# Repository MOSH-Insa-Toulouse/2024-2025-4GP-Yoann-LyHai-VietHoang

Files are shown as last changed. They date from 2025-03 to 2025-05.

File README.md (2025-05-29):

# Projet : Capteur Graphite à Crayon

## Table des matières
- [Projet : Capteur Graphite à Crayon](#projet--capteur-graphite-à-crayon)
  - [Table des matières](#table-des-matières)
- [Contexte](#contexte)
- [Réalisation du projet](#réalisation-du-projet)
  - [1. Matériaux utilisés](#1-matériaux-utilisés)
  - [2. Simulation électronique en utilisant LTSpice](#2-simulation-électronique-en-utilisant-ltspice)
    - [2.1 Fonctionnalité de condition nominale](#21-fonctionnalité-de-condition-nominale)
    - [2.2 Modélisation du capteur](#22-modélisation-du-capteur)
    - [2.3 Résultats visuels](#23-résultats-visuels)
    - [2.4 Simulation du signal alternatif](#24-simulation-du-signal-alternatif)
  - [3. Conception du circuit PCB en utilisant KiCad](#3-conception-du-circuit-pcb-en-utilisant-kicad)
    - [3.1 Réalisation des symboles et empreintes](#31-réalisation-des-symboles-et-empreintes)
    - [3.2 Réalisation du schéma électronique](#32-réalisation-du-schéma-électronique)
    - [3.3 Réalisation du PCB](#33-réalisation-du-pcb)
  - [4. Code Arduino](#4-code-arduino)
  - [5. Application Android codée avec MIT App Inventor](#5-application-android-codée-avec-mit-app-inventor)
    - [5.1. Initialisation](#51-initialisation)
    - [5.2. Composantes dans l'interface](#52-composantes-dans-linterface)
      - [Connection du Bluetooth:](#connection-du-bluetooth)
    - [Le bouton pour le capteur industriel (FlexSensor) et le capteur graphite](#le-bouton-pour-le-capteur-industriel-flexsensor-et-le-capteur-graphite)
    - [Le bouton "Mesure"](#le-bouton-mesure)
    - [Le bouton "Reset"](#le-bouton-reset)
    - [Bloc principal - Timer](#bloc-principal---timer)
    - [Le Graphique](#le-graphique)
  - [6. Réalisation du Shield](#6-réalisation-du-shield)
  - [7. Banc de test](#7-banc-de-test)
    - [7.1 Physique derrière le capteur en graphite](#71-physique-derrière-le-capteur-en-graphite)
    - [7.2 Résultats de mesures](#72-résultats-de-mesures)
  - [8. Datasheet](#8-datasheet)
- [Conclusion](#conclusion)
- [Références](#références)
- [Contacts](#contacts)
  - [Étudiants](#étudiants)
  - [Enseignants](#enseignants)

---

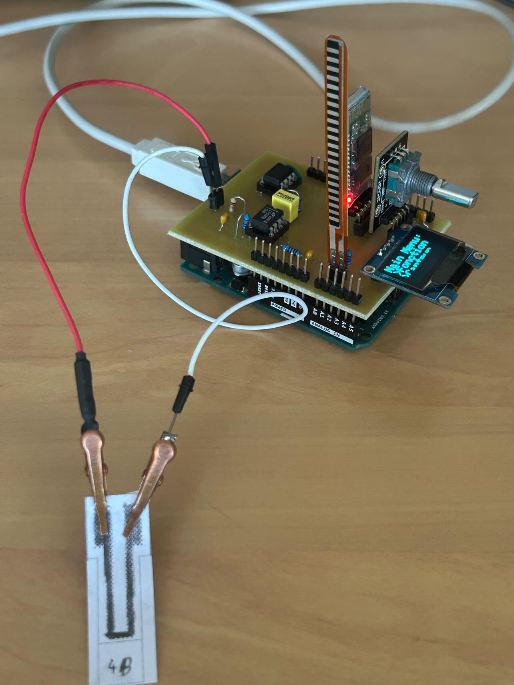
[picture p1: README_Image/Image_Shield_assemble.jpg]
Image de l'ensemble carte Arduino et capteur en graphite


# Contexte
Ce projet vise à développer un capteur basé sur du graphite de crayon de papier pour des applications en instrumentation. L'objectif est d'explorer les propriétés conductrices du graphite et de les exploiter dans un circuit électronique interactif.

---

# Réalisation du projet

---

## 1. Matériaux utilisés

Dans ce projet, nous utilisons des composants électroniques et des modules disponibles dans la salle d'instrumentation avec une carte Arduino UNO. Tous les composants sont listés ci-dessous :
   * 1 carte Arduino UNO Rev 3
   * 1 module Bluetooth (HC-05)
   * 1 encodeur rotatif (Keyes KY-040)
   * 1 écran OLED (SSD 1306)
   * 1 capteur de flexion commercial (LLC 1070)
   * 1 capteur en graphite fait à l'aide de la mine d'un crayon de papier
   * 1 amplificateur de transimpédance (LTC1050)
   * 1 potentiomètre numérique (MCP41100)
   * 2 supports IC pour le potentiomètre et l'amplificateur
   * 1 résistance 1kΩ, 1 résistance 10kΩ, 2 résistances 100kΩ
   * 3 condensateurs 100nF, 1 condensateur 1µF

---

## 2. Simulation électronique en utilisant LTSpice

### 2.1 Fonctionnalité de condition nominale

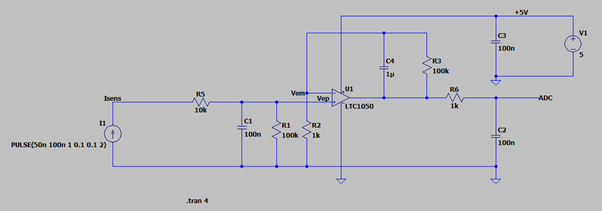
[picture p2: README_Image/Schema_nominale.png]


Le courant d’entrée Isens varie entre 50 nA et 100 nA, ce qui entraîne une variation de la tension Vep appliquée à l’entrée non-inverseur V+ du LTC1050, entre 5 mV et 10 mV.

Le gain de l’amplificateur du LTC1050 est défini par : G = 1 + R3/R2 = 101. Par conséquent, la valeur de la tension de sortie du LTC1050 varie entre 0.5 V et 1 V.

Simulation gain

Au départ, le signal exprimé en décibels est de 140 dB, ce qui correspond à :  
20 log(VADC / Isens).

Le microcontrôleur utilisé est un Arduino UNO, basé sur un microcontrôleur AVR avec une fréquence d’échantillonnage maximale fech = 200 kHz.  
Comme la conversion analogique-numérique se fait sur 13 bits, la fréquence d’échantillonnage réelle est limitée à 15.4 kHz.

D'après le théorème de Nyquist, la fréquence maximale du signal que l'on peut correctement numériser doit donc être inférieure à la moitié de cette valeur :  
fsignal < fech/2 = 7.7 kHz.

### 2.2 Modélisation du capteur

Le bruit à 50 Hz, généré notamment par l'écran TFT (bruit de type secteur), est clairement observé dans le spectre du signal. Pour l’atténuer, on agit sur le condensateur C4 du filtre passe-bas.

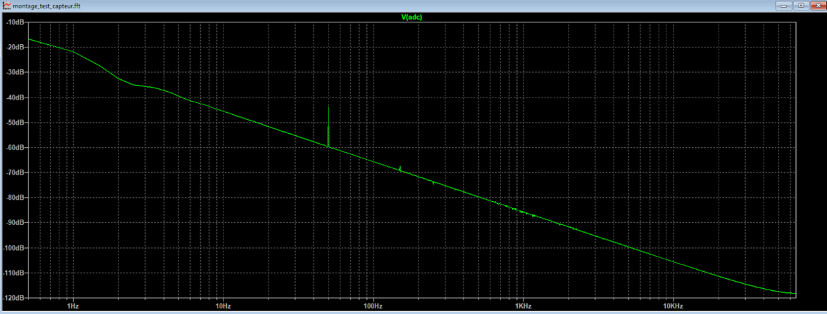
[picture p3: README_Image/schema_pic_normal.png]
Pic normal


- Lorsque la valeur de C4 est augmentée à 10 µF, le pic de bruit à 50 Hz est fortement réduit, ce qui indique une amélioration de l’atténuation dans les basses fréquences.

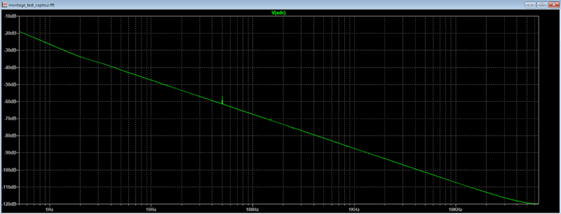
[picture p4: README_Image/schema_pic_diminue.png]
Pic diminue


- En revanche, si on diminue la valeur de C4, le bruit augmente, montrant que la fréquence de coupure du filtre remonte et que le bruit secteur passe plus facilement.

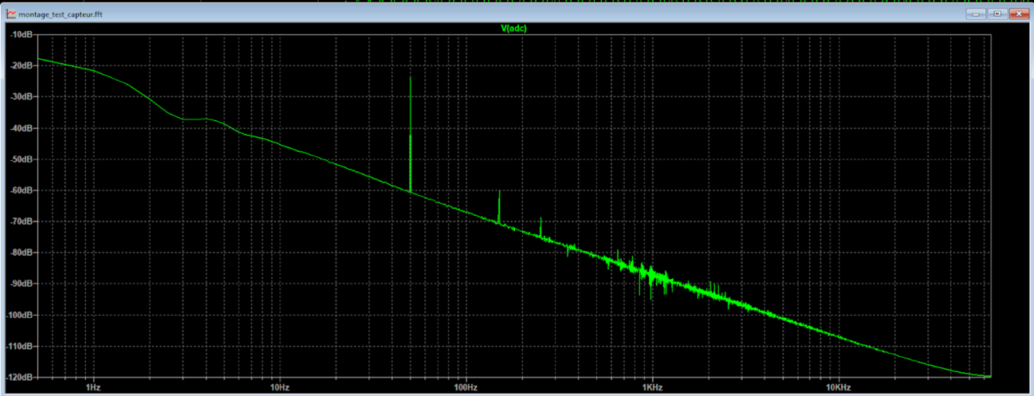
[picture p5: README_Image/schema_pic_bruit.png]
Pic bruit


### 2.3 Résultats visuels

Une photo démontrant que notre circuit permet une amplification efficace du signal délivré par le capteur :

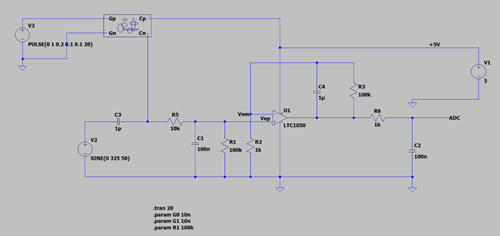
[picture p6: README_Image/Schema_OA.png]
Schema OA


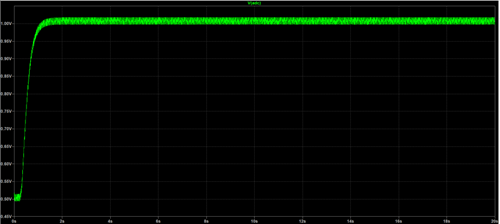
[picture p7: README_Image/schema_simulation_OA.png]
Simulation OA


### 2.4 Simulation du signal alternatif

Ensuite, on présente la réponse du circuit lorsque l'on simule un courant alternatif, afin de vérifier que le bruit est correctement filtré :

Le bruit du réseau est atténué d'environ 72 dB à 50 Hz.

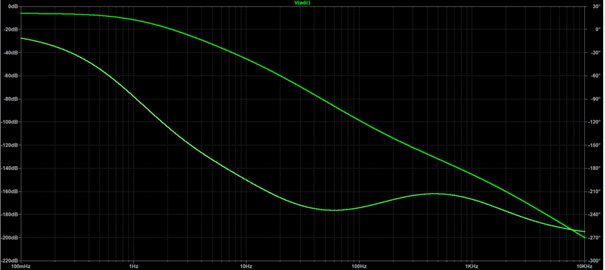
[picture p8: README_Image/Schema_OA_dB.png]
Schema OA dB


---

## 3. Conception du circuit PCB en utilisant KiCad

Afin de concevoir le circuit électronique, le logiciel en libre accès KICAD a été utilisé. L'ensemble des fichiers KiCad est disponible dans le dossier [Capteur_KICAD](./Capteur_KICAD).

### 3.1 Réalisation des symboles et empreintes

Pour commencer notre PCB (Printed Circuit Board), il est nécessaire de créer les symboles et les empreintes des composants qui ne sont pas disponibles dans la bibliothèque de KiCad. Nous avons réalisé les symboles du module Bluetooth, de l'encodeur rotatif, de l'écran OLED, du capteur de flexion et du capteur en graphite, afin de les ajouter au schéma de connexion. Ensuite, ces symboles ont été associés à une empreinte trouvée sur des sites de libre téléchargement.

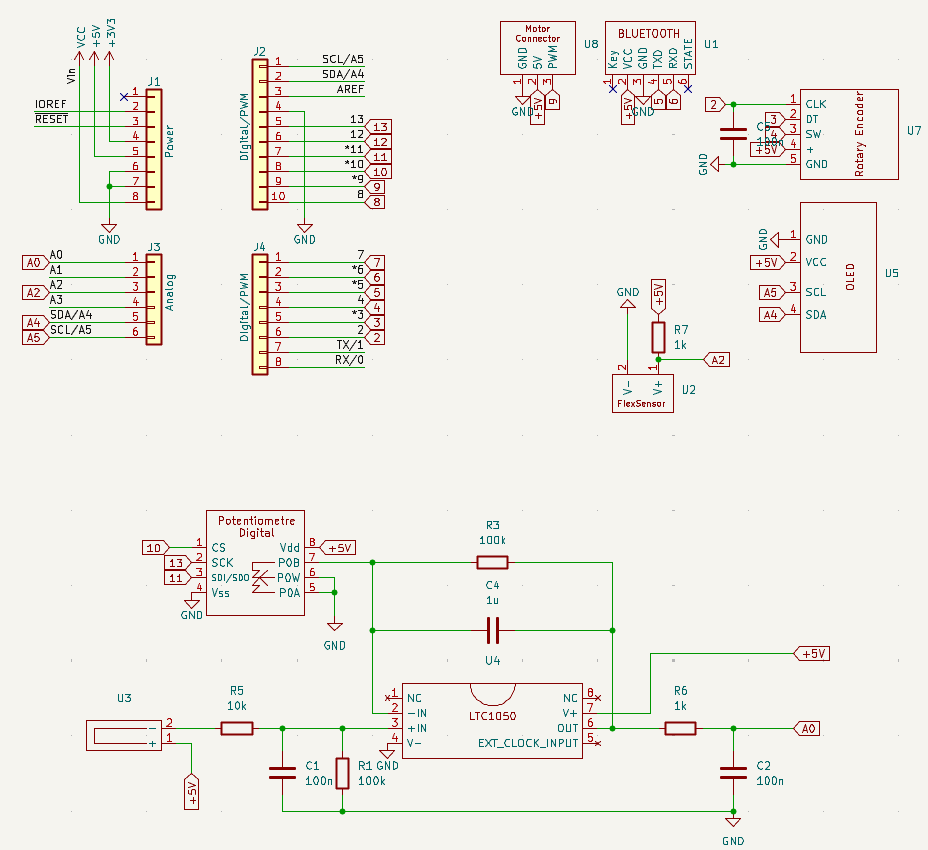
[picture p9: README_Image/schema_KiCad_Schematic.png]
Schéma électonique réalisé sur KiCad


### 3.2 Réalisation du schéma électronique

Ensuite, le schéma électronique est à construire. Dans cette partie, les différentes connexions entre composants sont définies et les pins de la carte Arduino sont attribués à chacun des composants.

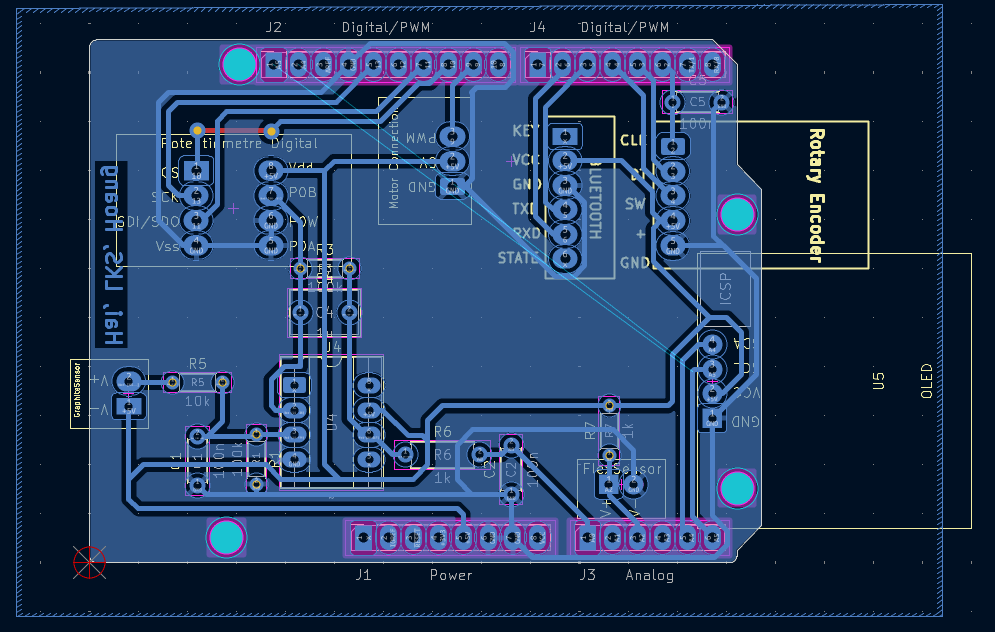
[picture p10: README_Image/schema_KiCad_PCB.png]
Schéma de routage du PCB sur KICAD


### 3.3 Réalisation du PCB

L'objectif ici était d'allouer un branchement sur les entrées d'une carte Arduino UNO à chaque module. Nous avons aussi pour but de faire le moins possible de via (pont traversant permettant de chavaucher un routage).
Le circuit imprimé a été dessiné avec une attention particulière portée à la disposition des pistes pour minimiser les couplages parasites et faciliter le routage manuel.

Schéma Conception du PCB sur KICAD

Les contraintes de branchement ont été les suivantes:
  * Encoder: pin clk -> pin 2 (Arduino)
  * Bluetooth: pin TXD -> la pin 5 (pin RXD de l'Arduino)
               pin RXD -> la pin 6 (pin TXD de l'Arduino)
  * Potentiomètre digital: pin SCK -> pin 13 (pin SCK de l'Arduino)
                           pin SDI -> pin 11 ()
  * FlexSensor: sur une pin analogue (A2 choisi)
  * Capteur Graphite: sur une pin analogue (A0 choisi)

Ensuite, l'impression du circuit s'est ensuite faite par méthode chimie:
  * Plaque de cuivre/résine dont la face en cuivre est enduite d'une résine photosensible;
  * Insolation de la résine sur les parties du cuivre non voulue;
  * Attaque chimique dans un bain révélateur;
  * Rinçage du circuit;

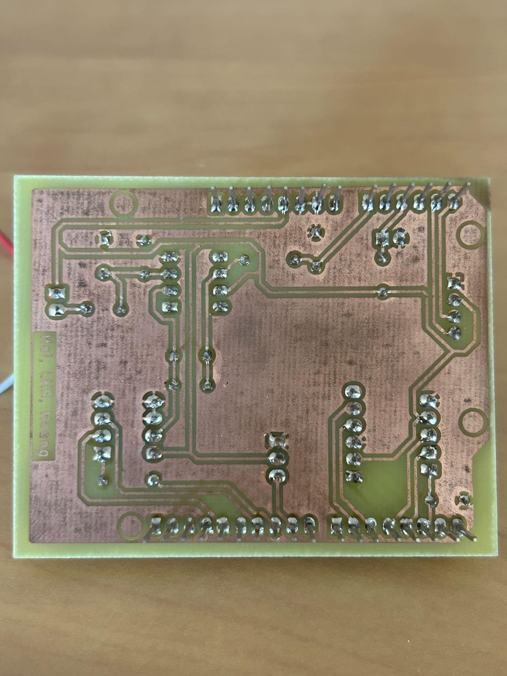
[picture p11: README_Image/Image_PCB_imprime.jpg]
Image montrant le PCB imprimé. Les soudures des composants sont aussi visibles


---

## 4. Code Arduino

Le code Arduino permet de lire les valeurs du capteur en graphite, de gérer l'affichage d'un Menu sur l'écran OLED, la communication par Bluetooth avec l'application Android (voir section [5. Application Android codée avec MIT App Inventor](#5.-Application-Android-codée-avec-MIT-App-Inventor)) et le contrôle via l'encodeur rotatif.
Le code arduino est disponible dans le dossier [Capteur_Arduino](./Capteur_Arduino).

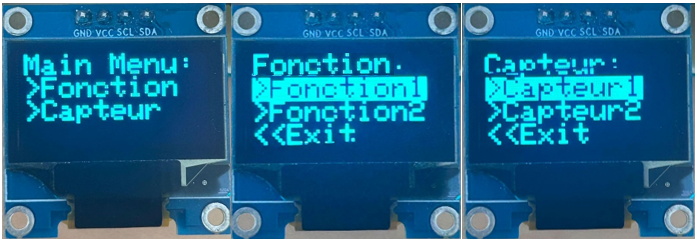
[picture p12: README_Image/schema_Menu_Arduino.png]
Image du menu


---

## 5. Application Android codée avec MIT App Inventor

Une application mobile a été développée pour :
- Recevoir les données en Bluetooth,
- Afficher les mesures en temps réel,
- Interagir avec le capteur de manière intuitive.
  
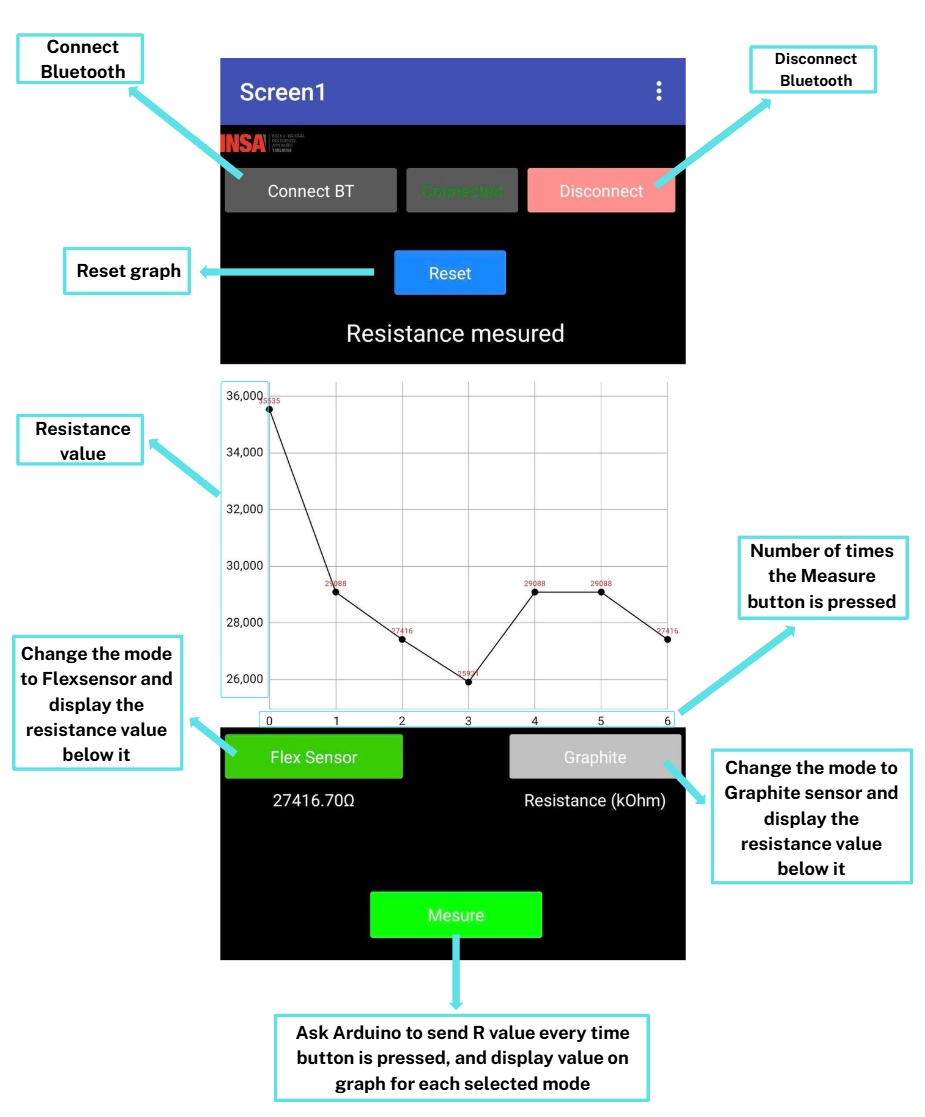
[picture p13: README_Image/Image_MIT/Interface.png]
Interface


### 5.1. Initialisation

  Nous avons déclaré les variables initiales utilisées dans le programme:

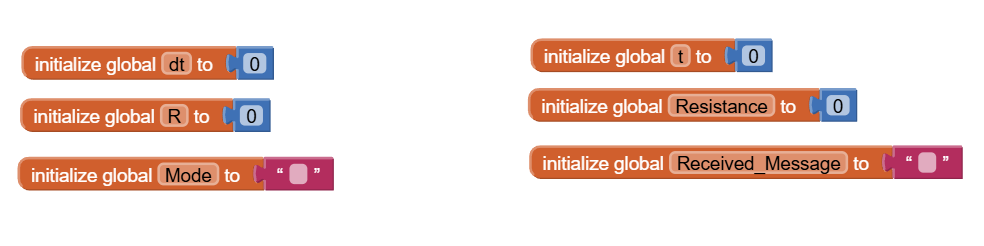
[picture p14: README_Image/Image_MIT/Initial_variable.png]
Variable initial
  

  Puis nous avons initialisé le programme:

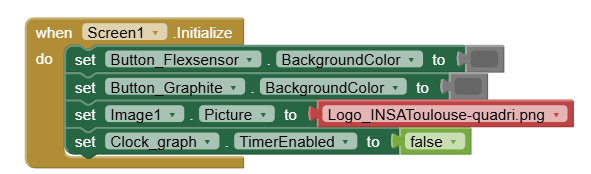
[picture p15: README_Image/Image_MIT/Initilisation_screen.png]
Demarrer screen
  

### 5.2. Composantes dans l'interface
---
#### Connection du Bluetooth:

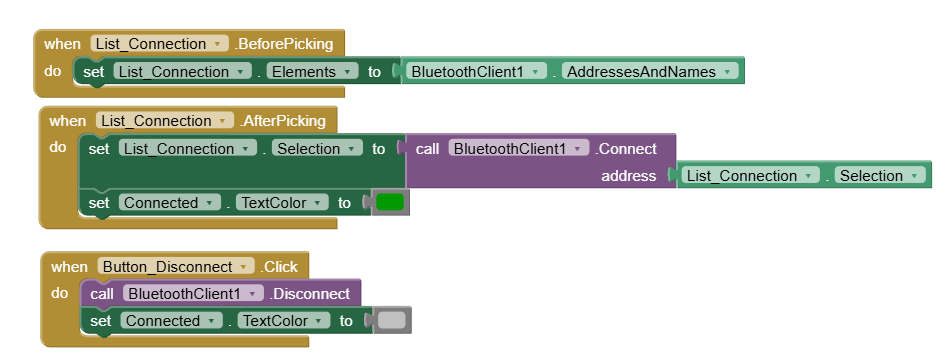
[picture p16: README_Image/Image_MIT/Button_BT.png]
Bouton BT

Le bouton « List_Connection » permet de sélectionner le module Bluetooth auquel on souhaite se connecter. Le bouton « Button_Disconnect » permet également de déconnecter le module Bluetooth sélectionné.

---

### Le bouton pour le capteur industriel (FlexSensor) et le capteur graphite

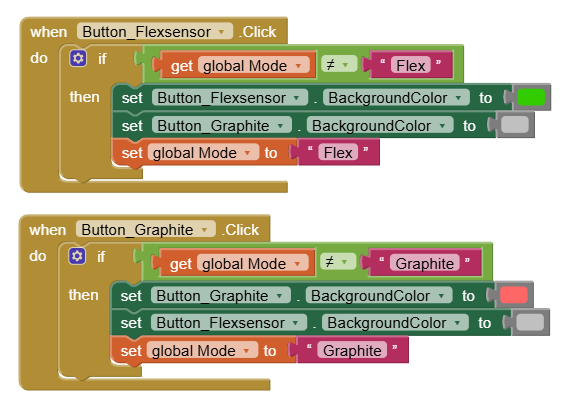
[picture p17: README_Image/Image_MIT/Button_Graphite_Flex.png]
Bouton Flex_Graphitesensor


Ces bouton permet de choisir le capteur que l'on veut afficher leur valeurs.

---
### Le bouton "Mesure"
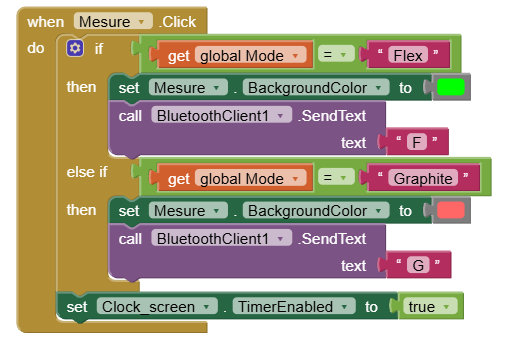
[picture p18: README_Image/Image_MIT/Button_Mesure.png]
Bouton Mesure


Ce bouton permet d'envoyer un message vers l'arduino via bluetooth pour lui demande de renvoyer les valeurs de resistances dependant le mode du capteur choisi.

---
### Le bouton "Reset"
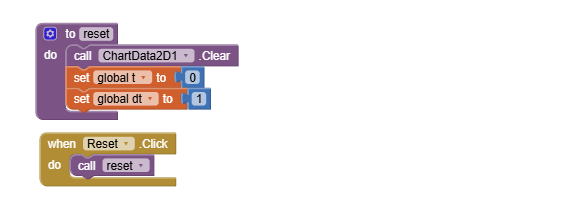
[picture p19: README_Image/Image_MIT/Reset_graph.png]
Reset Graph


Ce bouton permet de réinitialiser le graph.

---
### Bloc principal - Timer
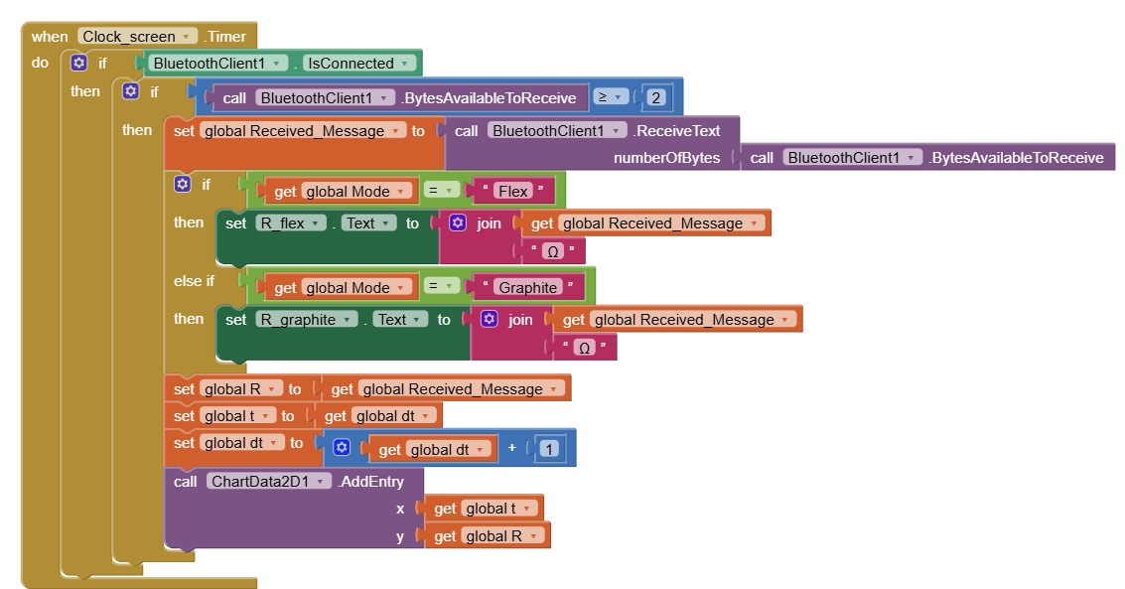
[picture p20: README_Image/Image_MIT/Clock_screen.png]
Timer

Pour pouvoir récupérer automatiquement des données, on commande séquentiellement Arduino de nous evoyer les données. Pour cela, on utilise le composante "Clock"dans MIT. 

---
### Le Graphique
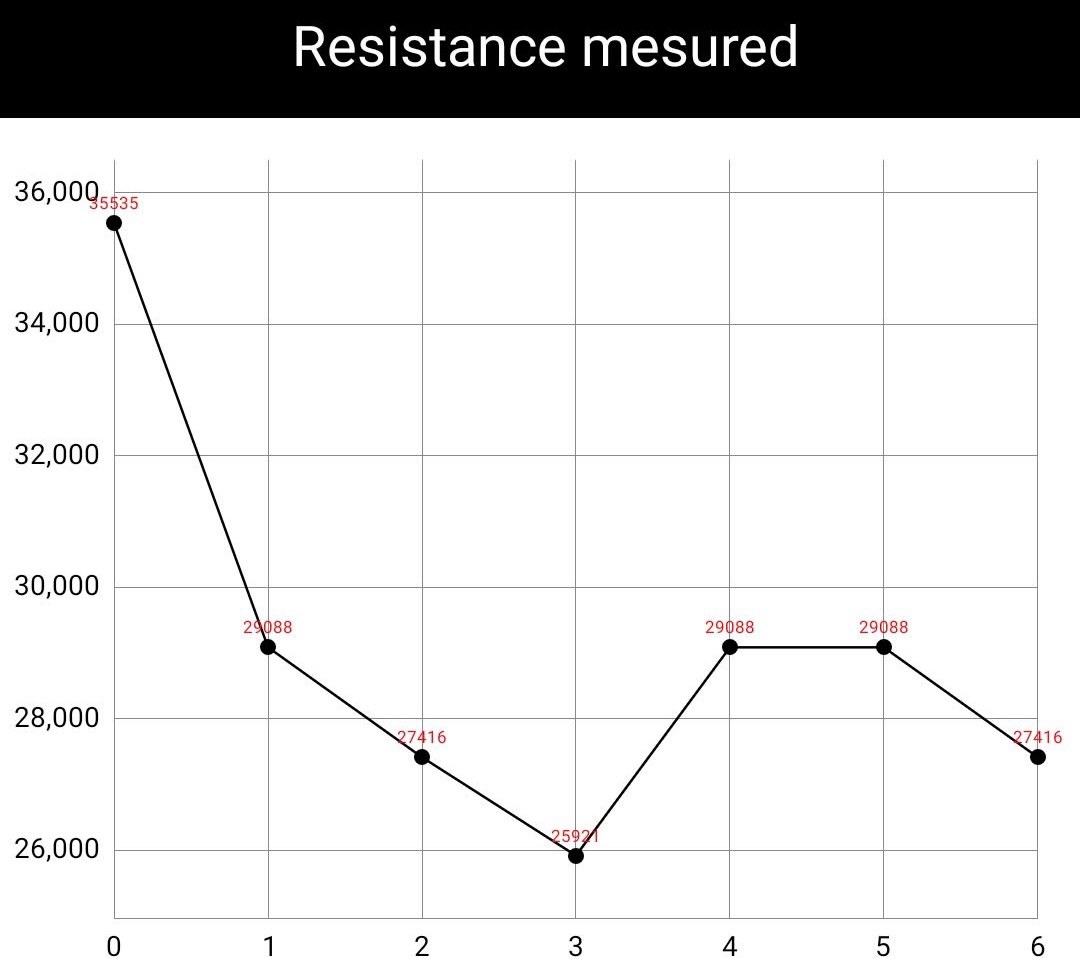
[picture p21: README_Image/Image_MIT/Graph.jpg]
Graph


Le graphique montre le variation de résistance du capteur FlexSensor et du capteur graphite à chaque mesure.

## 6. Réalisation du Shield

Pour la réalisation du shield, nous avons manuellement soudé l'ensemble des modules arduino et composants électroniques (résistances, capacités, amplificateur opérationnel) au PCB imprimé. (voir section [3.4 Réalisation du PCB](#34-réalisation-du-pcb)).

Le Shield réalisé intègre un amplificateur de signal LTC1050 pour amplifier les faibles signaux des capteurs avec précision, un encodeur rotatif permettant de naviguer dans le menu et de modifier les valeurs de résistance via un potentiomètre, un écran OLED pour afficher clairement les menus et les informations, ainsi qu’un module Bluetooth assurant la communication sans fil avec un téléphone portable pour le contrôle et la supervision à distance du système.

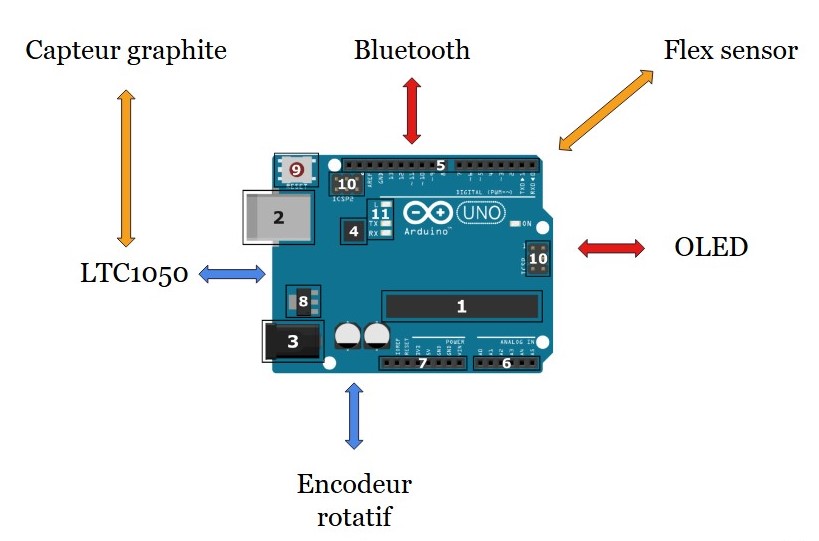
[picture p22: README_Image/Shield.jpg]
shield


---

## 7. Banc de test

Afin de valider le fonctionnement du système, plusieurs tests ont été réalisés :
- Mesure des signaux et tensions aux bornes des capteurs et calcul de résistance.
- Test de communication Bluetooth.
- Et prise de mesures de résistance issues du capteur en graphite.

Un modèle 3D composé de fentes circulaires de différents rayons est utilisé pour le banc de test. En insérant le capteur dans ces fentes, une déformation est induite en fonction de son orientation (traction ou compression). La déformation est inversement proportionnelle au rayon des fentes circulaires, selon la relation suivante : ε = e / R

  Où :  
  - ε : déformation 
  - e : allongement imposé  
  - R : rayon de la fente (0,2 mm)

Ce système permet de contrôler précisément la déformation du capteur en choisissant simplement un rayon de fente spécifique.

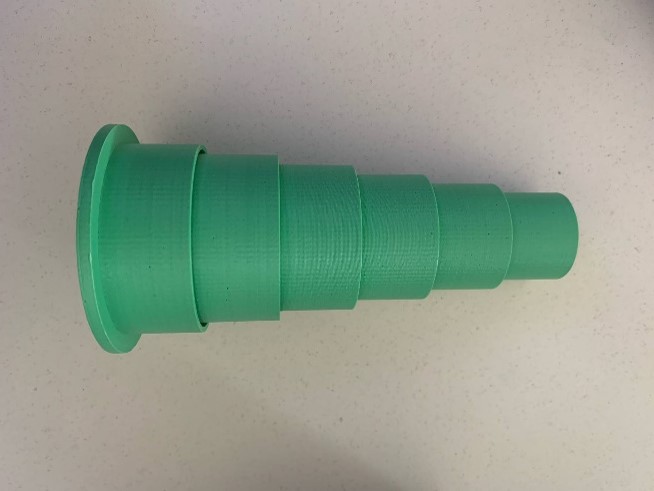
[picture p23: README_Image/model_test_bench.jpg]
model_test_bech


### 7.1 Physique derrière le capteur en graphite

Une variation de la résistance du capteur est attendue lorsque ce dernier est déformé. Cette variation est notamment dû au rapprochement ou à l'éloignement des atomes de carbone.
Lorsque le capteur est mis en tension, les atomes de carbone ont tendance à s'écarter. Ainsi, moins d'atome sont en contact afin de créer une chaîne reliant les deux extrémités du cpateur. Les électrons passent plus difficilement, la résistance augmente donc.
Lorsque le capteur est mis en compression, les atomes de carbone se rapprochent. La configuration est plus favorable à la création de chaîne reliant les deux extrémités du capteur. Les électrons passent plus facilement, la résistance diminue donc.
Par ailleurs, il est attendu à ce que la résistance diminue en même temps que la dureté du crayon de papier augmente. Cela peut simplement s'expliquer par une réduction de la présence de carbone.

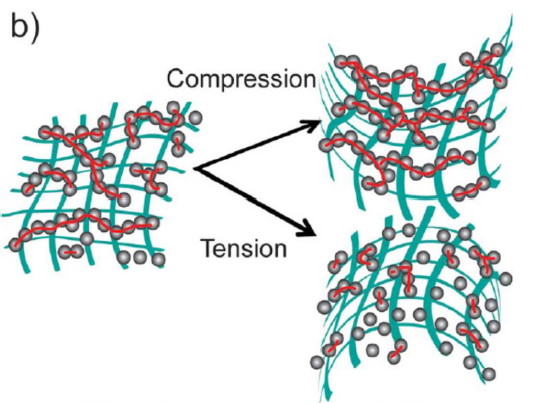
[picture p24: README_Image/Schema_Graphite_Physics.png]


La résistance peut s'exprimer comme suivant:

Schéma

  Où :
  - "l" la longueur de la couche de nanoparticule (graphite) ;
  - "a" le paramètre de maille de la matrice cubique centrée du graphite ;
  - "w" la largeur, et "d" l'épaisseur du film.
Quant à la résistance "R12", elle est obtenue en posant les équations de mécanique quantique appliquée à des nanoparticules :

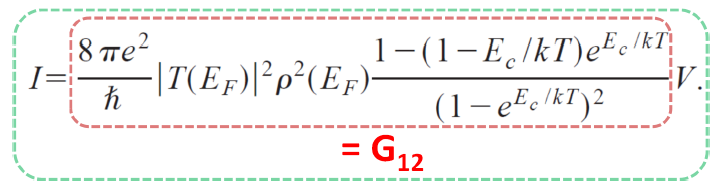
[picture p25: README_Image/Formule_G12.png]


Schéma

Pour plus d'informations, les sources utilisées sont fournies dans la rubrique [Références](#références).

### 7.2 Résultats de mesures

Par la suite, nous avons caractérisé notre capteur en graphite afin de retrouver les résultats de l'étude dont la source est donnée ci-dessus. La tension aux bornes du capteur est mesurée, puis convertie en valeur de résistance. Cette valeur de résistance est affichée en fonction de la déformation appliquée sur le capteur.
Les graphiques ci-dessus montrent la variation relative de la valeur du capteur en fonction de la déformation dans deux modes : traction et compression. Des droites de régression linéaire passant par l’origine ont été tracées. Ces lignes théoriques démontrent que la valeur de ΔR/R₀ varie linéairement avec la déformation.

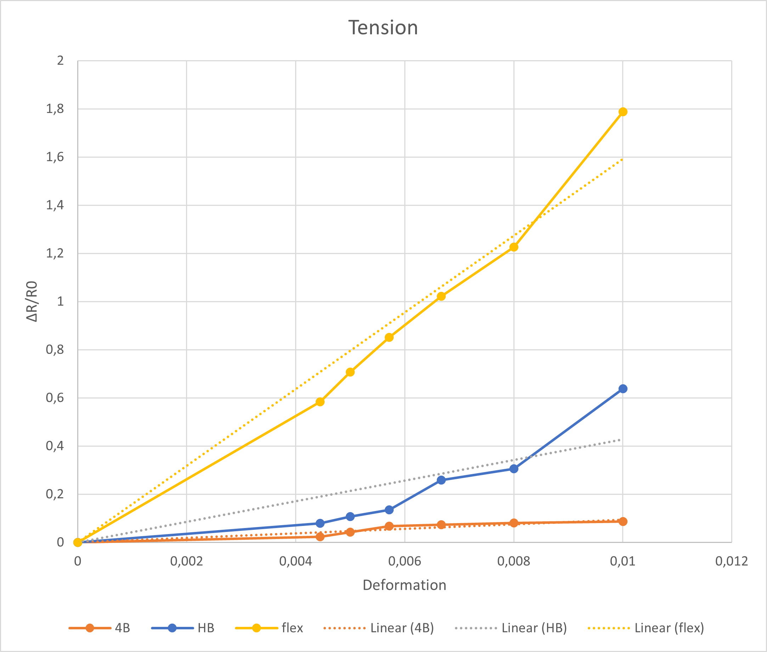
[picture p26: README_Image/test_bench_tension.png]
test_bench_tension


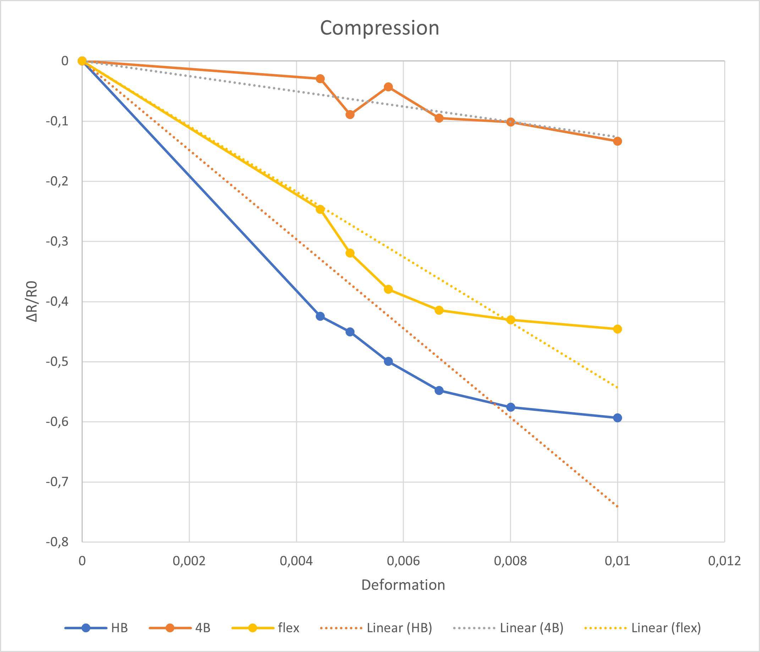
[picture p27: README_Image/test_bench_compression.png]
test_bench_compression


---

## 8. Datasheet
Les fiches techniques des principaux composants (LTC1050, HC-05, écran OLED, etc.) sont disponibles dans le dossier [datasheet_graphit_sensor.pdf](./Datasheet/datasheet_graphit_sensor.pdf) du projet. Par ailleurs, une documentation sur notre capteur graphite est disponible sur ce Github.

---

# Conclusion
Ce projet démontre la faisabilité d’un capteur à base de graphite de crayon pour des applications d’instrumentation. Le prototype final est capable de détecter des variations de résistance liées à la pression exercée sur le graphite. Néanmoins, la faible répétabilité des mesures et de la confection du capteur en graphite ne permet pas une industrialisation. On note aussi que durant le test, le graphite du capteur est en contact avec les parois. Cela pourrait engendrer un retrait de graphite à chaque insertion.
Les points d'amélioration pouvant être apportés sont : une amélioration du banc de test, la normalisation du dépôt de graphite.

Une documentation de notre capteur est aussi disponible ([Documentation Capteur Graphite](./Datasheet/Datasheet_graphit_sensor.pdf))

---

# Références
- Fiches techniques des composants (HC-05, Keyes KY-040, SSD 1306, LLC 1070, LTC1050, MCP41100)
- Documentation Arduino
- Tutoriels MIT App Inventor
- Outils de simulation LTSpice et KiCad

<ins>Sources sur l'étude du capteur en graphite :</ins>

"Pencil Drawn Strain Gauges and Chemiresistors on Paper
Cheng-Wei Lin*, Zhibo Zhao*, Jaemyung Kim & Jiaxing Huang
Department of Materials Science and Engineering,
Northwestern University 2220 Campus Drive, Evanston, IL, 60208, USA.
SCIENTIFIC REPORTS | 4 : 3812 | DOI: 10.1038/srep03812 - 2014"

"Electron transport in nanoparticle assemblies
K.-H. Müller1, J. Herrmann2, G. Wei1, B. Raguse1, and L.Wieczorek1
1Future Manufacturing Flagship, 1CSIRO Materials Science and Engineering
Lindfield NSW2070, Australia
2NationalMeasurement Institute, Lindfield NSW 2070, Australia
978-1-4244-5262-0/10/$26.00 © 2010 IEEE - ICONN 2010"

"Percolation model for electron conduction in films of metal nanoparticles linked by organic molecules
K.-H. Müller,* J. Herrmann, B. Raguse, G. Baxter, and T. Reda
Commonwealth Scientific and Industrial Research Organization, Telecommunications and Industrial Physics,
Sydney 2070, Australia
PHYSICAL REVIEW B 66, 075417 (2002)"

---

# Contacts

## Étudiants
- **Yoann Lai Koun Sing** : laikouns@insa-toulouse.fr  
- **Viet Hoang Pham** : vpham@insa-toulouse.fr  
- **Ly Hai Hoang** : lhoang@insa-toulouse.fr  

## Enseignants
- **Jérémie Grisolia** : jeremie.grisolia@insa-toulouse.fr  
- **Arnauld Biganzoli** : arnauld.biganzoli@insa-toulouse.fr  
- **Cathy Crouzet** : crouzet@insa-toulouse.fr  
- **Benjamin Mestre** : benjamin.mestre@scalian.com

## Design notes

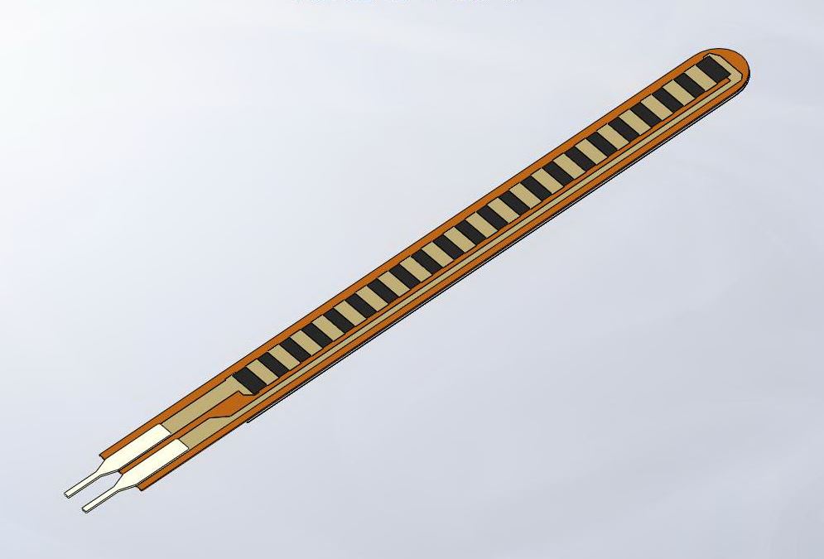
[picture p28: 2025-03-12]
Capteur_KICAD/Librairie_Model3D/flex-sensor-spectra-symbol-1.snapshot.2/Renderings/Flex Sensor.JPG

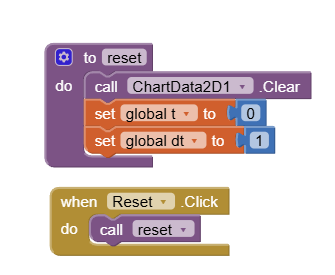
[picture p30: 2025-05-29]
README_Image/Image_MIT/Button_resetgraph.png

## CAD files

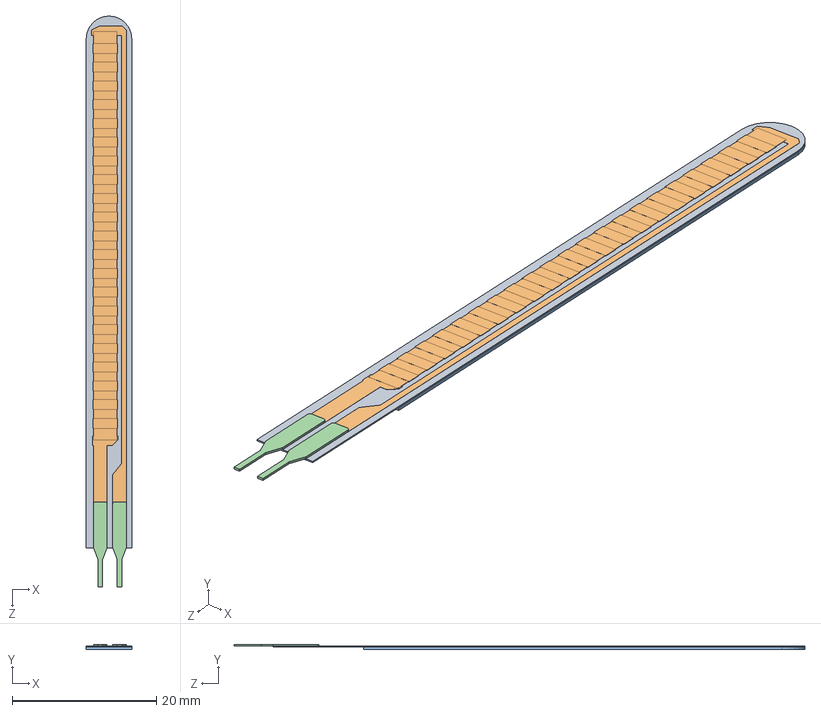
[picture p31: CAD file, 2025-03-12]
Capteur_KICAD/Librairie_Model3D/flex-sensor-spectra-symbol-1.snapshot.2/Flex Sensor/FlexSensor.SLDASM
6.35 x 0.648 x 79.3 mm
PlasticFilm
Flex_Sensor_Circuit
Plastic_Stiffner
GoldProngTerminal x 2

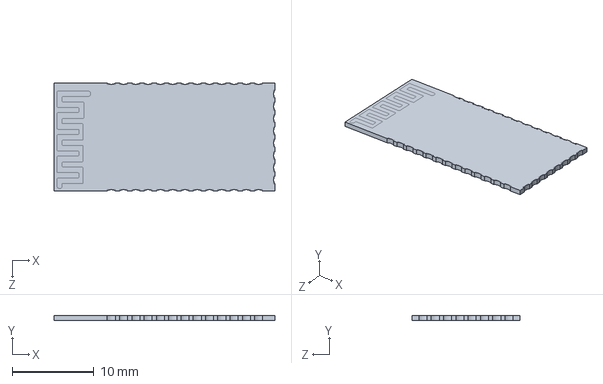
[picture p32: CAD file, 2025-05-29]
Capteur_KICAD/Librairie_Model3D/bluetooth-module-hc-05-1.snapshot.4/Bluetooth Module HC-05/HC-05 part3.SLDPRT
27.0 x 0.61 x 13.2 mm

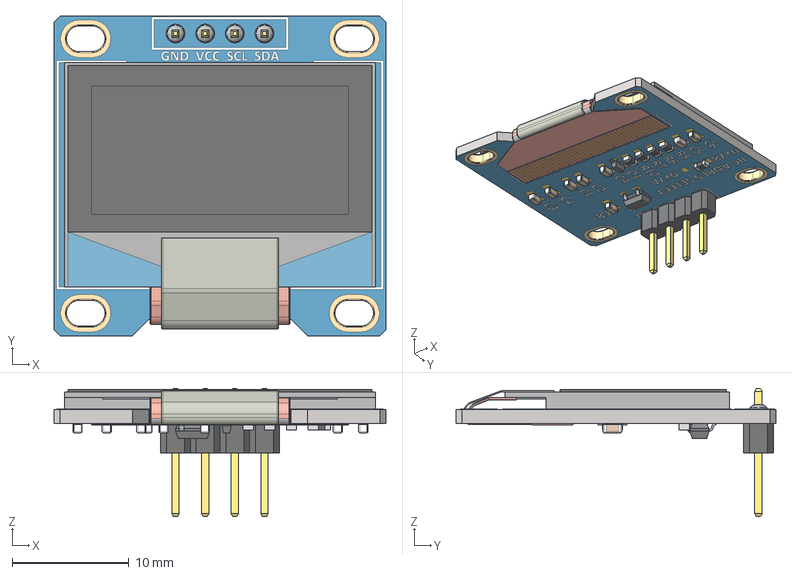
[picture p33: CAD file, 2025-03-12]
Capteur_KICAD/Librairie_Model3D/pantalla-oled-0-96-128x64-1.snapshot.7/Pantalla OLED 0.96'' 128x64.stp
28.4 x 27.4 x 11.0 mm
SOT-23_TOR
RES_CR16_MTK_1 x 4
RES_CR16_MTK
SOD323F_DIO

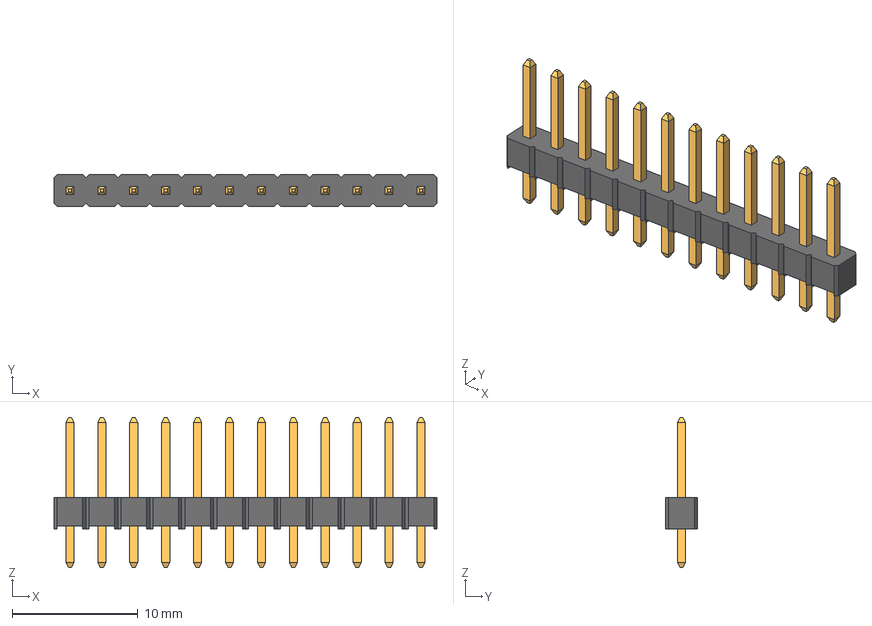
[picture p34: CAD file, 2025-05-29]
Capteur_KICAD/Librairie_Model3D/pin-header-male-2-54mm-different-pin-numbers-1.snapshot.2/12-Pin Header - Male - 2.54mm.step
30.5 x 2.54 x 11.9 mm

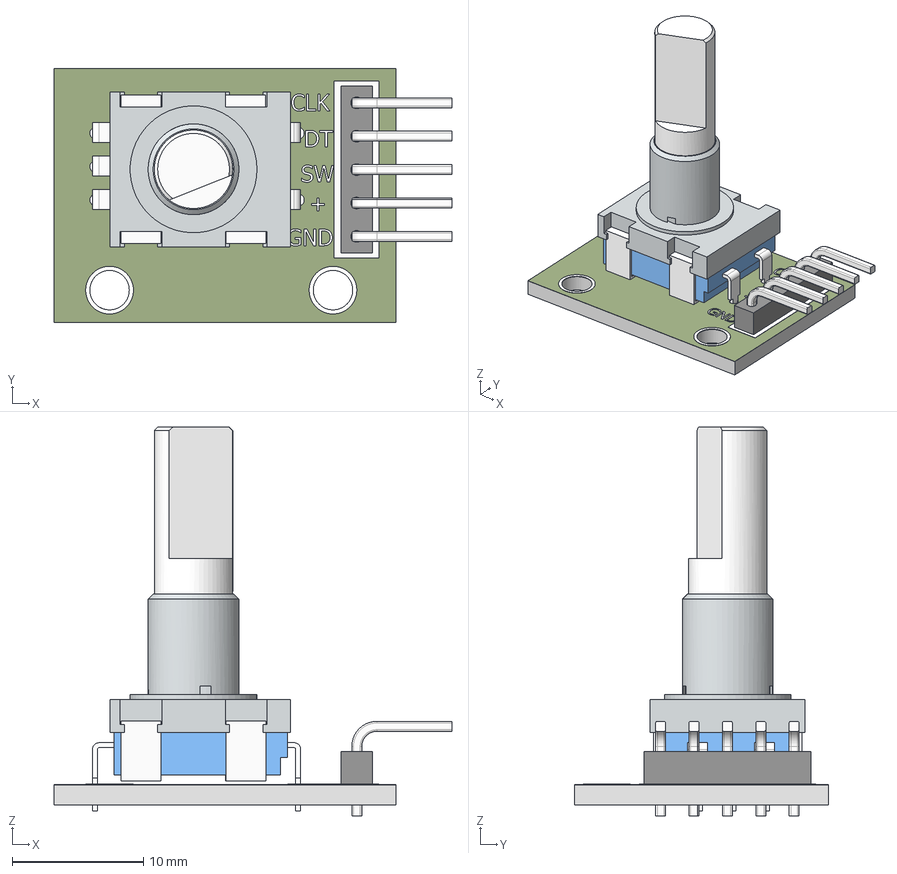
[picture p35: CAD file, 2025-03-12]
Capteur_KICAD/Librairie_Model3D/rotary-encoders-1.snapshot.1/rotary+encoder_17mm_hole_spc.stp
30.3 x 19.3 x 29.6 mm
pcb
mtg flange
body_encoder
5 pin header
90d pin_header x 5
decal_encoder
pins_encoder body_2 x 5
shaft_encoder

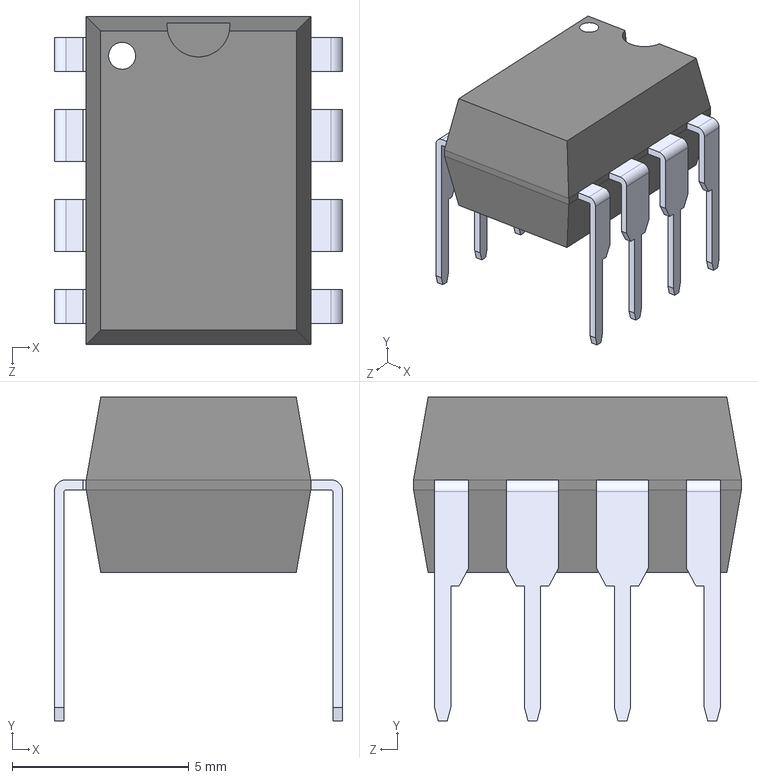
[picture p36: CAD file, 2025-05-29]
Capteur_KICAD/LTC1050ACN8_PBF/LTC1050ACN8_PBF.step
8.15 x 9.14 x 9.27 mm

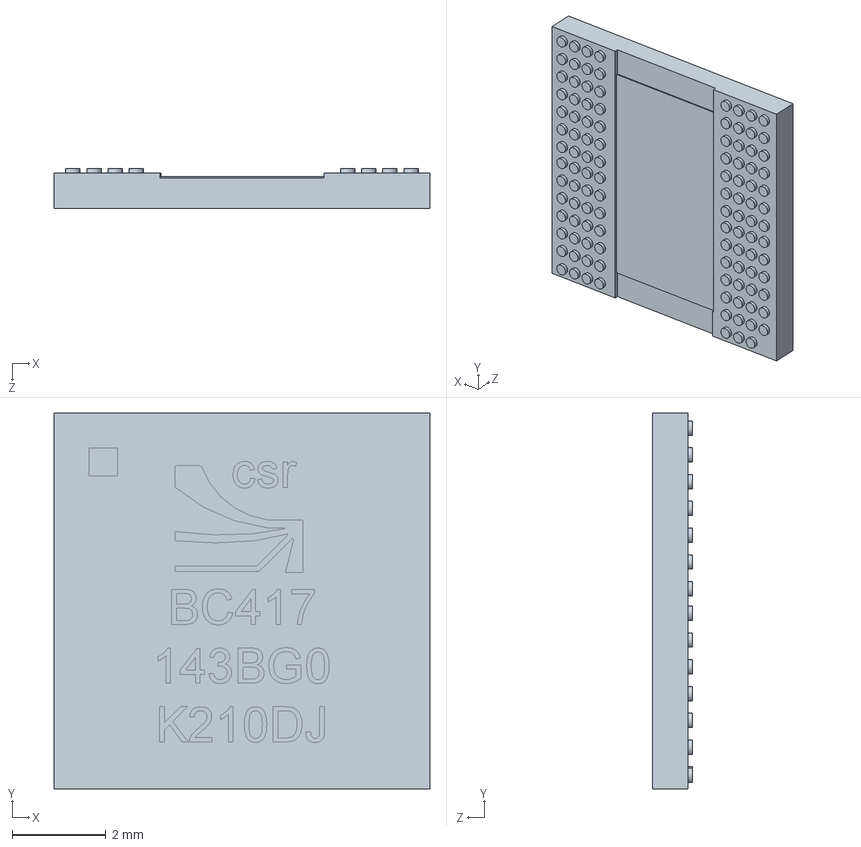
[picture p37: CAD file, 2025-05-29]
Capteur_KICAD/Librairie_Model3D/bluetooth-module-hc-05-1.snapshot.4/Bluetooth Module HC-05/HC-05 part2.SLDPRT
8.00 x 8.00 x 0.85 mm

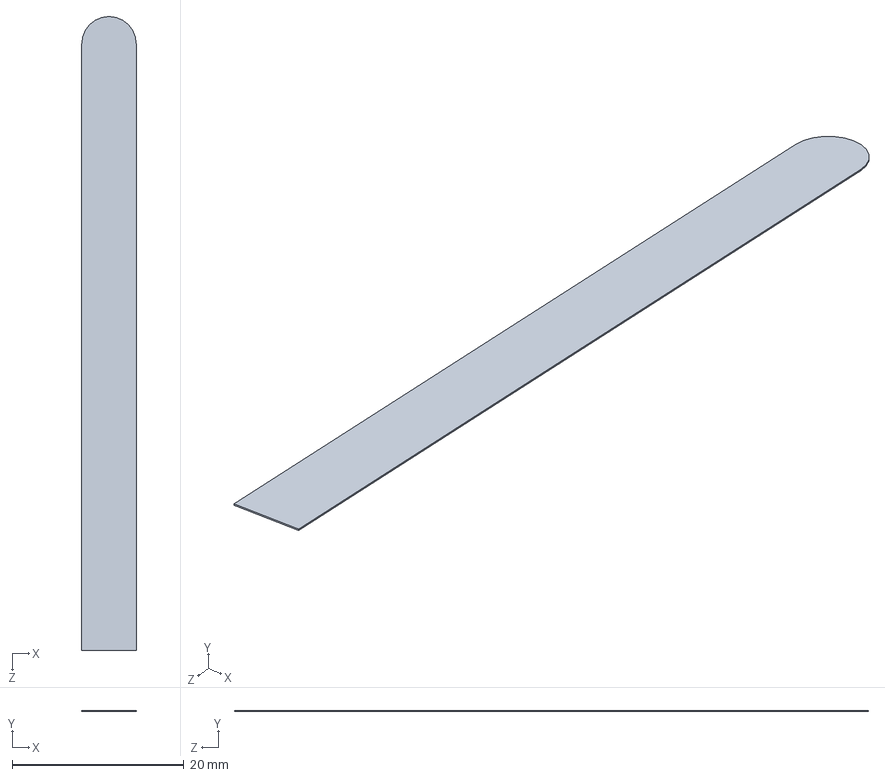
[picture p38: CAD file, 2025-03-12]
Capteur_KICAD/Librairie_Model3D/flex-sensor-spectra-symbol-1.snapshot.2/Flex Sensor/PlasticFilm.SLDPRT
6.35 x 0.127 x 73.8 mm

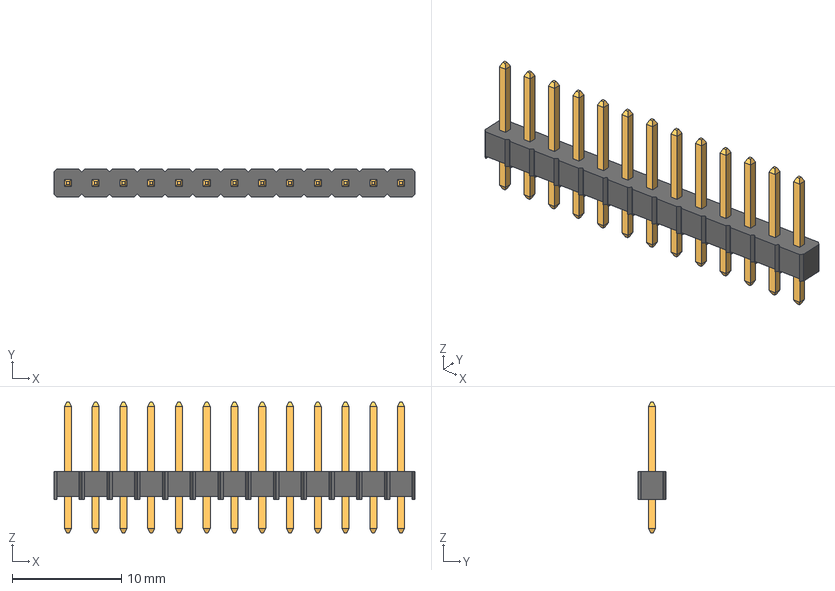
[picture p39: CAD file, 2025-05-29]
Capteur_KICAD/Librairie_Model3D/pin-header-male-2-54mm-different-pin-numbers-1.snapshot.2/13-Pin Header - Male - 2.54mm.step
33.0 x 2.54 x 11.9 mm

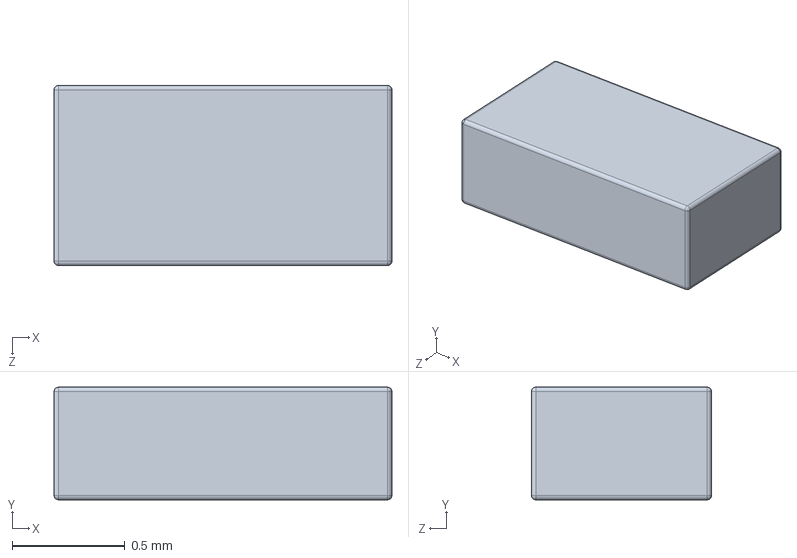
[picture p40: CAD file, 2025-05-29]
Capteur_KICAD/Librairie_Model3D/bluetooth-module-hc-05-1.snapshot.4/Bluetooth Module HC-05/HC-05 part10.SLDPRT
1.50 x 0.5 x 0.8 mm

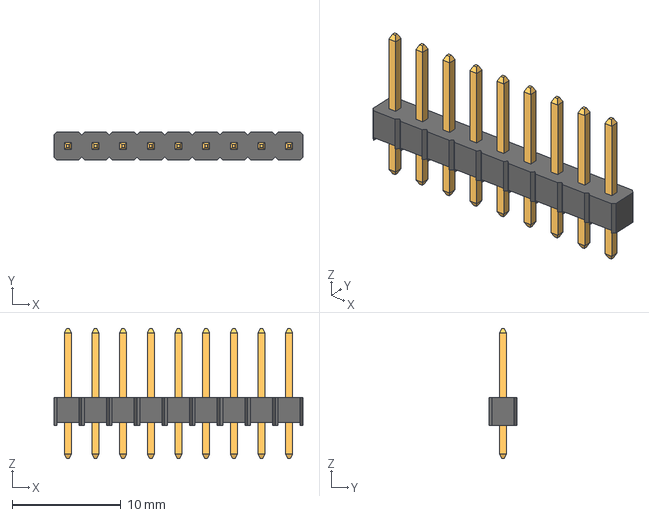
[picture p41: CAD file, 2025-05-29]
Capteur_KICAD/Librairie_Model3D/pin-header-male-2-54mm-different-pin-numbers-1.snapshot.2/9-Pin Header - Male - 2.54mm.step
22.9 x 2.54 x 11.9 mm

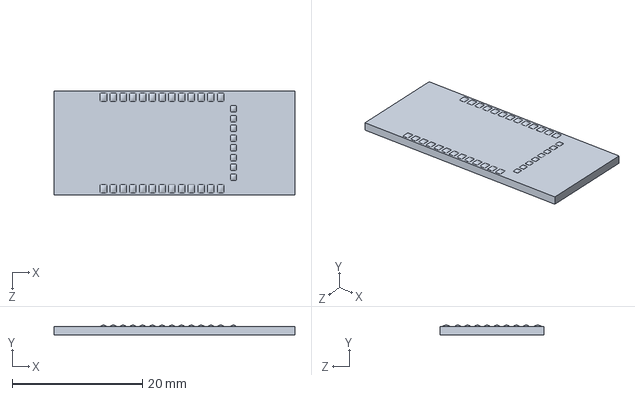
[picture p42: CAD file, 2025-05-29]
Capteur_KICAD/Librairie_Model3D/bluetooth-module-hc-05-1.snapshot.4/Bluetooth Module HC-05/HC-05 part1.SLDPRT
37.0 x 1.51 x 16.0 mm

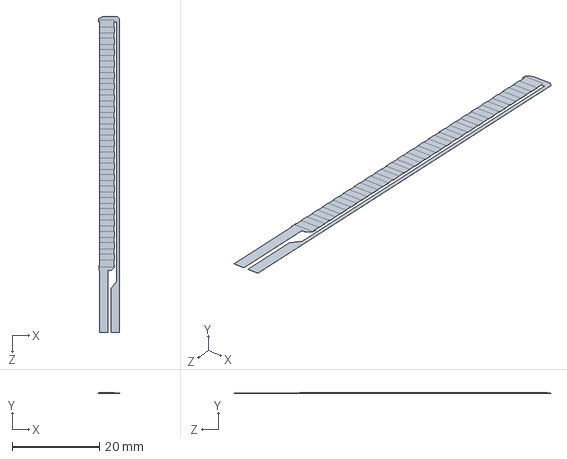
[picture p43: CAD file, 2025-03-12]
Capteur_KICAD/Librairie_Model3D/flex-sensor-spectra-symbol-1.snapshot.2/Flex Sensor/Flex_Sensor_Circuit.SLDPRT
4.83 x 0.0381 x 72.4 mm

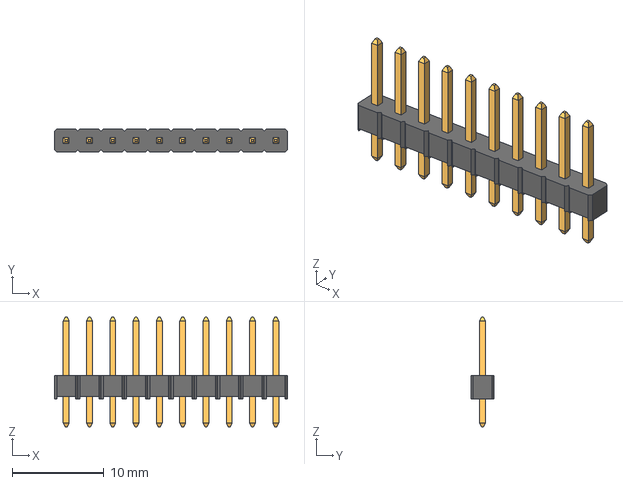
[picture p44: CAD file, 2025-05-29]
Capteur_KICAD/Librairie_Model3D/pin-header-male-2-54mm-different-pin-numbers-1.snapshot.2/10-Pin Header - Male - 2.54mm.step
25.4 x 2.54 x 11.9 mm

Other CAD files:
Capteur_KICAD/Librairie_Model3D/rotary-encoders-1.snapshot.1/rotary+encoder_14mm_hole_spc.stp
Capteur_KICAD/Librairie_Model3D/flex-sensor-spectra-symbol-1.snapshot.2/Flex Sensor/Plastic_Stiffner.SLDPRT
Capteur_KICAD/Librairie_Model3D/bluetooth-module-hc-05-1.snapshot.4/Bluetooth Module HC-05/HC-05 part5.SLDPRT
Capteur_KICAD/Librairie_Model3D/bluetooth-module-hc-05-1.snapshot.4/Bluetooth Module HC-05/HC-05 part11.SLDPRT
Capteur_KICAD/Librairie_Model3D/bluetooth-module-hc-05-1.snapshot.4/Bluetooth Module HC-05/HC-05 part12.SLDPRT
Capteur_KICAD/Librairie_Model3D/bluetooth-module-hc-05-1.snapshot.4/Bluetooth Module HC-05/HC-05 part4.SLDPRT
Capteur_KICAD/Librairie_Model3D/bluetooth-module-hc-05-1.snapshot.4/Bluetooth Module HC-05/HC-05 part6.SLDPRT
Capteur_KICAD/Librairie_Model3D/bluetooth-module-hc-05-1.snapshot.4/Bluetooth Module HC-05/HC-05 part7.SLDPRT
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

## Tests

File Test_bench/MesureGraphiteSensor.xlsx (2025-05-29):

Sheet: Feuil1
 | Graphite Sensor
 | Crayon 2HB
 | Rayon de courbure (m) | Déformation (m) | Tension | Resistance (ohm)
 | 0 | 0 | 4.99 | 80146904
 | 0.01 | 10
 | 0.0125 | 8
 | 0.015 | 6.666666667
 | 0.0175 | 5.714285714
1 | 0.02 | 5 | 2.52 | 158692912
 | 0.0225 | 4.444444444
2 | 0.025 | 4 | 2.35 | 170603136
3 | 0.03 | 3.333333333 | 2.31 | 173129536
4 | 0.035 | 2.857142857 | 1.96 | 203726560
 | 0.04 | 2.5
 | 0.045 | 2.222222222
0 | 1 | 0.1
1 | 0.045 | 2.222222222 | 2.52 | 158692912
2 | 0.04 | 2.5 | 2.35 | 170603136
3 | 0.035 | 2.857142857 | 2.31 | 173129536
4 | 0.03 | 3.333333333 | 1.96 | 203726560
5 | 0.025 | 4 | 1.99 | 201222432
6 | 0.02 | 5 | 1.95 | 205259168
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

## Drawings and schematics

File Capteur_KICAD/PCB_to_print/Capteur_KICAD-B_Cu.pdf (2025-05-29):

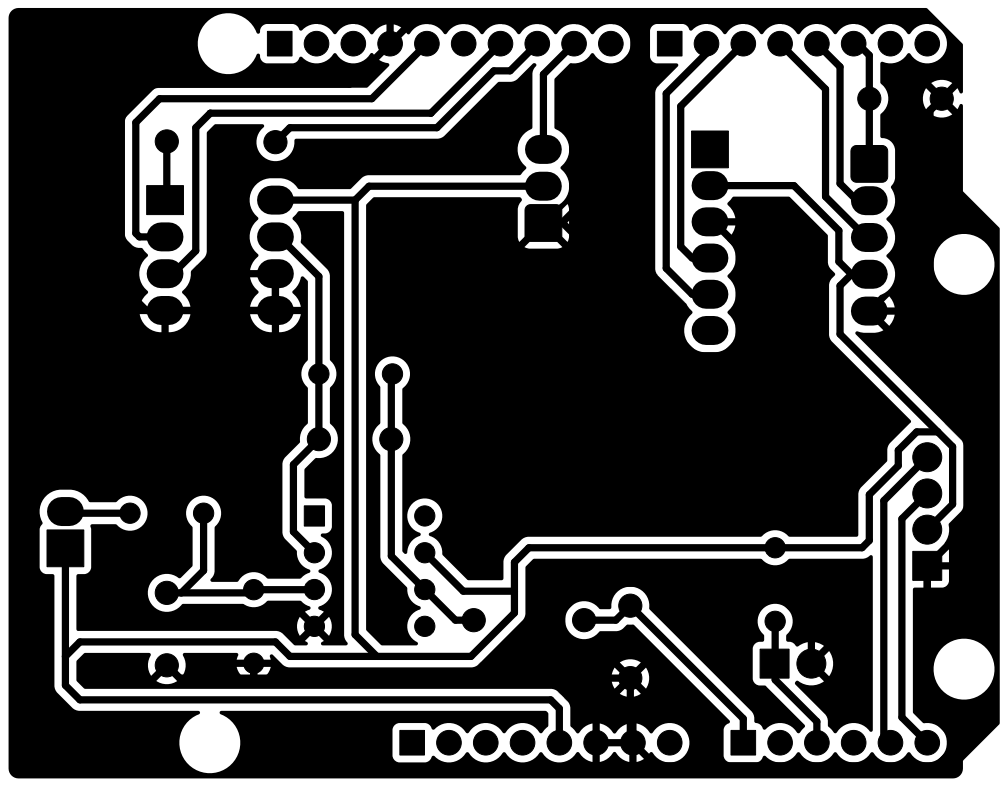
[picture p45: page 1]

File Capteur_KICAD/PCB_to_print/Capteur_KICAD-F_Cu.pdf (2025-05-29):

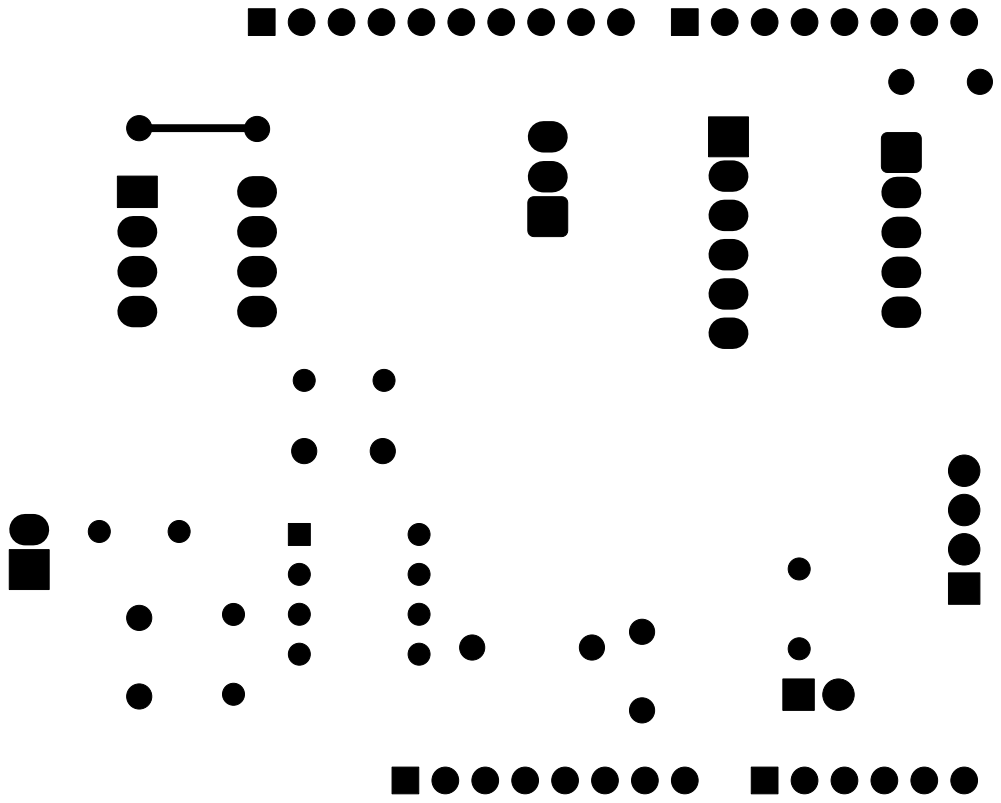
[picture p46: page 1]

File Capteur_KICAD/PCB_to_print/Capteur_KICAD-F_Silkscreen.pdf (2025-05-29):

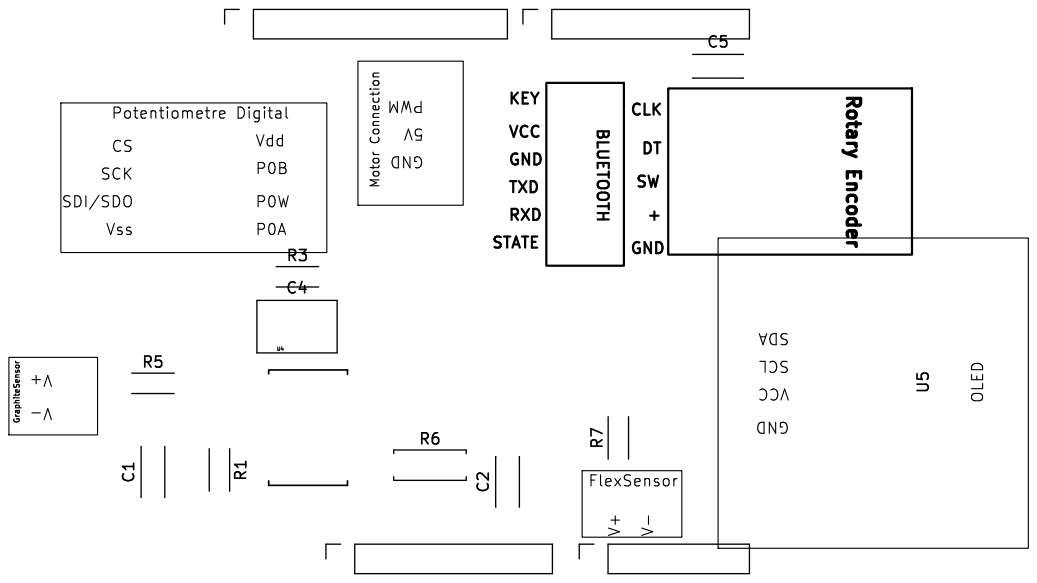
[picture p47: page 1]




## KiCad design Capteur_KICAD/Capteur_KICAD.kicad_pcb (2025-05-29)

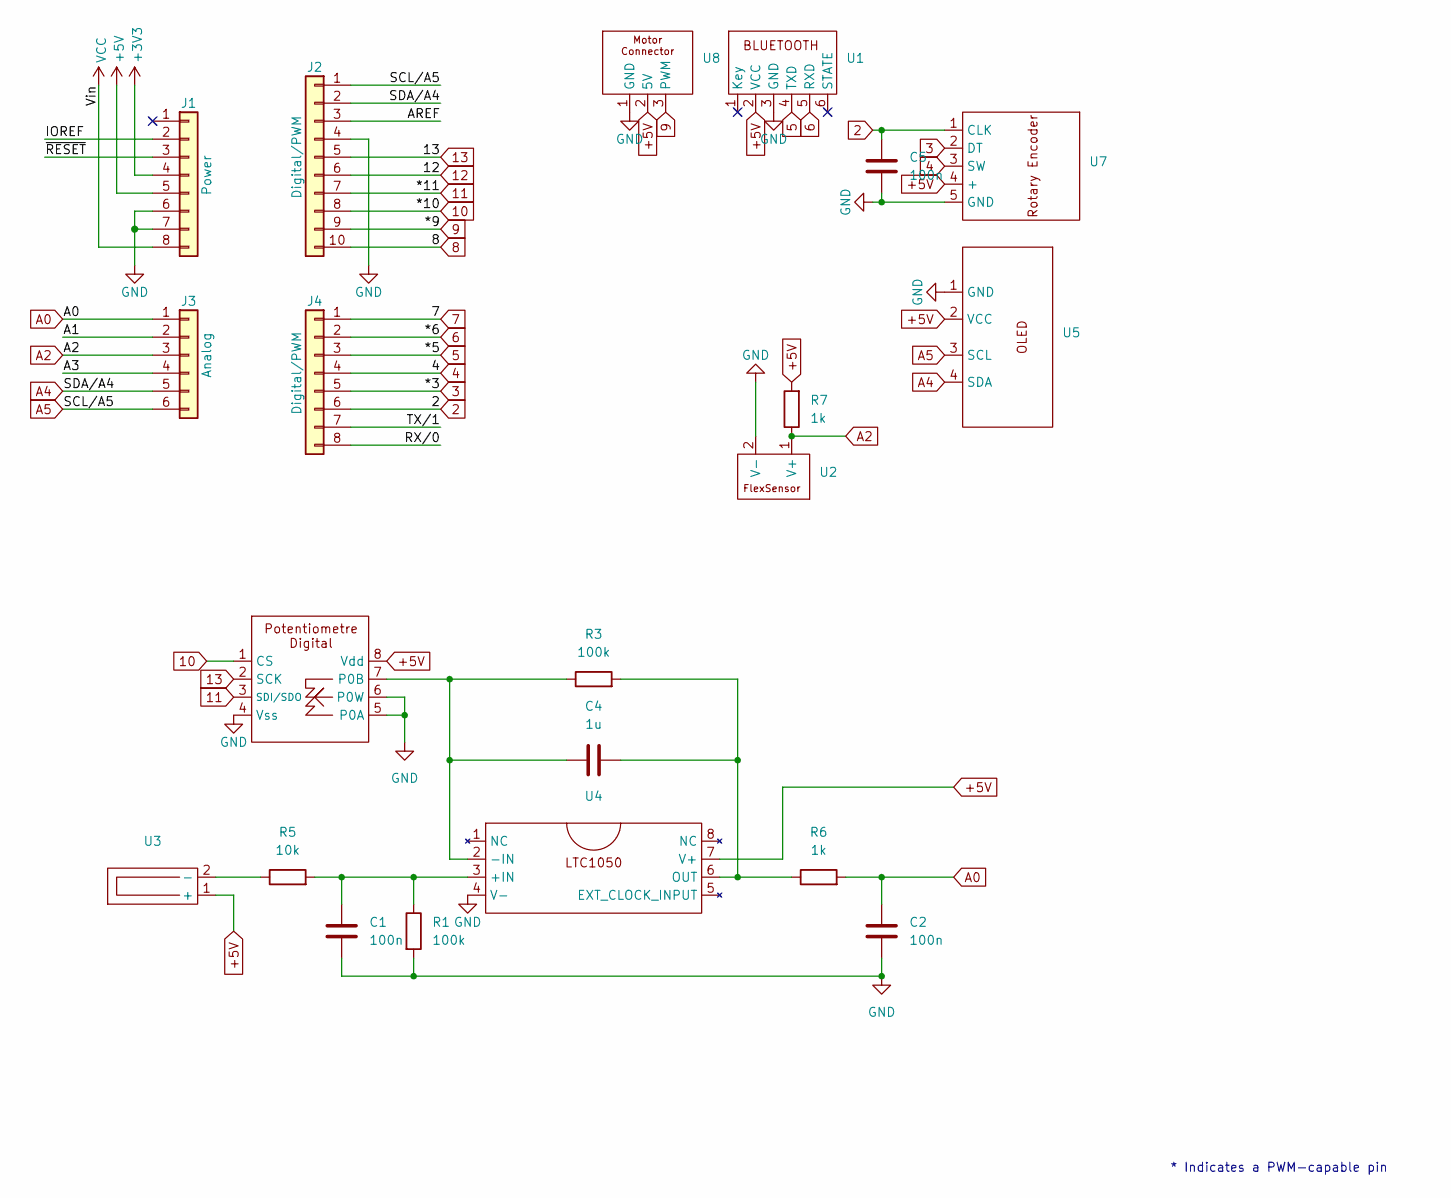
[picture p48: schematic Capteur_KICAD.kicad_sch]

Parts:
C1, C2, C5: 100n; C_Disc_D4.3mm_W1.9mm_P5.00mm
C4: 1u; C_Rect_L7.0mm_W4.5mm_P5.00mm
J1: Power; PinSocket_1x08_P2.54mm_Vertical
J2: Digital/PWM; PinSocket_1x10_P2.54mm_Vertical
J3: Analog; PinSocket_1x06_P2.54mm_Vertical
J4: Digital/PWM; PinSocket_1x08_P2.54mm_Vertical
R1, R3: 100k; R_Axial_DIN0204_L3.6mm_D1.6mm_P5.08mm_Horizontal
R5: 10k; R_Axial_DIN0204_L3.6mm_D1.6mm_P5.08mm_Horizontal
R6: 1k; R_Axial_DIN0207_L6.3mm_D2.5mm_P7.62mm_Horizontal
R7: 1k; R_Axial_DIN0204_L3.6mm_D1.6mm_P5.08mm_Horizontal
U1: Empreinte_Bluetooth
U2: Empreinte_FlexSensor
U3: Empreinte_GraphiteSensor
U4: CERDIP-8_W7.62mm_SideBrazed_LongPads_Socket
U5: Empreinte_OLED
U6: Empreinte_PotentiometreDigital
U7: Empreinte_Rotary_Encoder
U8: Empreinte_ConnecteurMoteur

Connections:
2: C5.1, J4.6, U7.1 (CLK)
3: J4.5, U7.2 (DT)
4: J4.4, U7.3 (SW)
5: J4.3, U1.4 (TXD)
6: J4.2, U1.5 (RXD)
7: J4.1
8: J2.10
9: J2.9, U8.3 (PWM)
10: J2.8, U6.1 (CS)
11: J2.7, U6.3 (SDI/SDO)
12: J2.6
13: J2.5, U6.2 (SCK)
+3V3: J1.4
+5V: J1.5, R7.2, U1.2 (VCC), U3.1 (+), U4.7 (V+), U5.2 (VCC), U6.8 (Vdd), U7.4 (+), U8.2 (5V)
/A1: J3.2
/A3: J3.4
/AREF: J2.3
/IOREF: J1.2
/RX/0: J4.8
/TX/1: J4.7
/~RESET: J1.3
A0: C2.2, J3.1, R6.2
A2: J3.3, R7.1, U2.1 (V+)
A4: J2.2, J3.5, U5.4 (SDA)
A5: J2.1, J3.6, U5.3 (SCL)
GND: C1.1, C2.1, C5.2, J1.6, J1.7, J2.4, R1.2, U1.3 (GND), U2.2 (V-), U4.4 (V-), U5.1 (GND), U6.4 (Vss), U6.5 (P0A), U6.6 (P0W), U7.5 (GND), U8.1 (GND)
unnamed: R5.1, U3.2 (-)
unnamed: C1.2, R1.1, R5.2, U4.3 (+IN)
unnamed: C4.1, R3.1, U4.2 (-IN), U6.7 (P0B)
unnamed: C4.2, R3.2, R6.1, U4.6 (OUT)
VCC: J1.8

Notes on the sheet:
* Indicates a PWM-capable pin

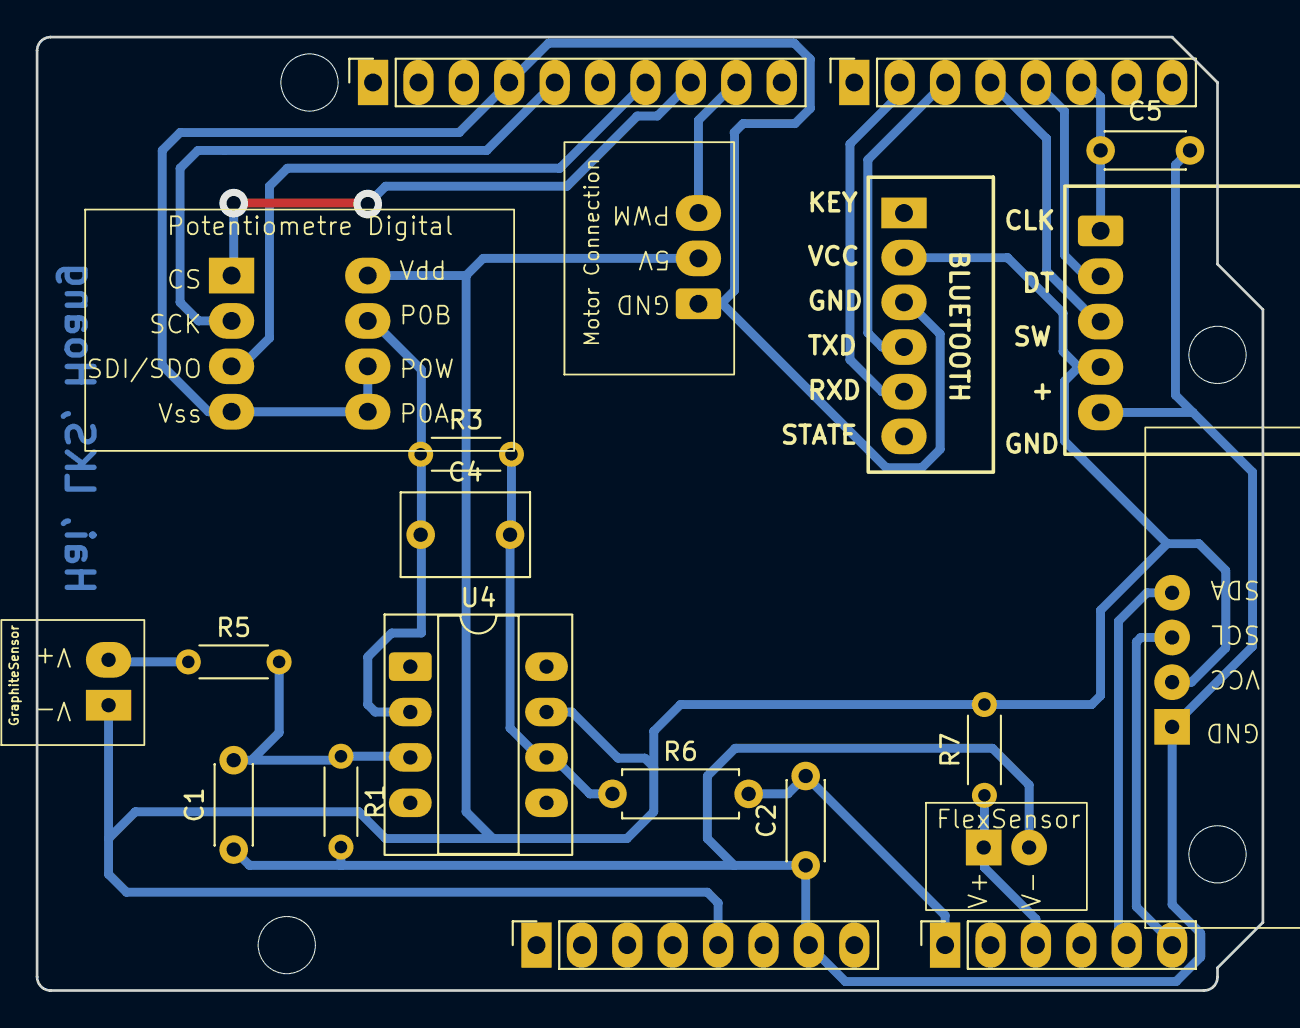
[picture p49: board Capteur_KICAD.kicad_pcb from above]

Board: 2 copper layers, 68.6 x 53.3 mm, 25 parts (0 on the bottom side), 19 nets.

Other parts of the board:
MH1, MH2, MH3, MH4: MountingHole_3.2mm

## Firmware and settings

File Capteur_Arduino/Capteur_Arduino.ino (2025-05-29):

/*
==============================================
=============== Projet Capteur ===============
==============================================
Authors: Yoann LAI KOUN SING, Viet Hoang PHAM, Ly Hai HOANG
Last update: 29/05/2025
*/


//====================================================
//==================== Libraries =====================
//====================================================

#include <Adafruit_SSD1306.h>  // Library of the OLED screen
#include <Wire.h>              // Library of the OLED screen
// #include <Servo.h>             // Library of the servo motor     BIBLIOTHEQUE Servo PAS UTILISABLE AVEC SoftwareSerial
#include <SPI.h>               // Library for SPI to control Digital Potentiometer
#include <SoftwareSerial.h>    // Library for HC-05 bluetooth module
#include <stdlib.h>


//====================================================
//==================== Declaration ===================
//====================================================

// _____ OLED Screen _____
#define nombreDePixelsEnLargeur 128
#define nombreDePixelsEnHauteur 64
#define brocheResetOLED -1
#define adresseI2CecranOLED 0x3C
Adafruit_SSD1306 ecranOLED(nombreDePixelsEnLargeur, nombreDePixelsEnHauteur, &Wire, brocheResetOLED);
// _____ Rotary Encoder _____
#define pinEncoder_CLK 2  // CLK output
#define pinEncoder_DT 3   // DT Output
#define pinEncoder_SW 4   // Switch connection
volatile int encoderPos = 0;
volatile int encoderPosBefore = 0;
volatile int encoderButton = 0;
volatile int encoderButtonBefore = 0;
volatile int MenuPos = -1;
volatile int MenuPosBefore = -1;
int buttonState;
int lastButtonState = HIGH;
long lastDebounceTime = 0;
long debounceDelay = 50;
// _____ Digital Potentiometer _____
// #define pinPot_CS 10      //pin 10 to control Digital Potentiometer
const byte pinPot_CS = 10;
#define pinPot_SCK 13
#define pinPot_SDI 11
const int  maxPositions = 256;
const long rAB = 52700;
const byte rWiper = 125; 
const byte pot0 = 0x11;
const byte pot0Shutdown = 0x21;
volatile float R_pot = 0 ;
// _____ Flex Sensor _____
#define pinFlexSensor A2            // Pin connected to voltage divider output
const float VCC = 5.0;                   // Voltage at Ardunio 5V line
const float R_DIV = 1000;                // Resistor [ohm] used to create a voltage divider
const float flatResistance = 35994.36;   // Resistance when flat
const float bendResistance = 120000.0;   // Resistance at 90 deg bending (80000)
// _____ Graphite Sensor _____
#define pinGraphiteSensor A0
volatile float R_graphite = 0 ;
const float R1 = 100000;      // Resistance in [ohm]
const float R3 = 100000;      // Resistance in [ohm]
const float R5 = 10000;       // Resistance in [ohm]
const float R6 = 1000;        // Resistance in [ohm]
const float C1 = 0.0000001;   // Capa in [F]
const float C2 = 0.0000001;   // Capa in [F]
const float C4 = 0.000001;   // Capa in [F]
// _____ Bluetooth _____
#define pinBT_TXD 6
#define pinBT_RXD 5
#define BTbuffer 8
SoftwareSerial MyBT(pinBT_RXD, pinBT_TXD) ;
volatile float DataToSend = 0.0 ;
// _____ Motor _____
#define pinMoteur 9
                       // Create an object My_servo to communicate with the Servo-motor
// _____ Other Parameters _____
#define baudrate 9600
const int DeltaTime = 200 ;
unsigned long currentTime;
unsigned long previousTime = 0;


//====================================================
//====================== Setup =======================
//====================================================
void setup() {
  Serial.begin(baudrate);
  // _____ OLED Screen _____
  Set_OLED();
  // _____ Bluetooth _____
  MyBT.begin(9600);
  InitBluetooth();
  // _____ Rotary Encoder _____
  Set_RotaryEncoder();
  attachInterrupt(digitalPinToInterrupt(pinEncoder_CLK), doEncoder, RISING);
  // _____ Digital Potentiometer _____
  Set_DigitalPotentiometer();
  // _____ Flex Sensor _____
  pinMode(pinFlexSensor, INPUT);
  digitalWrite(pinFlexSensor, LOW);
  // _____ Graphite Sensor _____
  pinMode(pinGraphiteSensor, INPUT);
  // attachInterrupt(digitalPinToInterrupt(pinBT_RXD), ReceiveDataBluetooth, RISING);
  // _____ Servo Moteur _____
  pinMode(pinMoteur, OUTPUT);
  digitalWrite(pinMoteur, LOW);
  // 
  Serial.println();
  Serial.println("----- Programme Capteur Start -----");
}


//====================================================
//==================== Main Loop =====================
//====================================================
void loop() {
  // Button of the Rotary encoder
  doEncoderButton();
  
  // Refresh OLED screen at each iteration
  DisplayOLED();
  
  // Get sensor mesurement
  currentTime = millis();
  if ((currentTime - previousTime >= DeltaTime) && ( (ChoixCapteur == 110) || (ChoixCapteur == 111) )  ){
    previousTime = currentTime ;
    Sensor_Mesurement(ChoixCapteur);
  }
  
  // Receive message from Bluetooth
  char received_message[32]={0};
  if (MyBT.available() > 0){
    int i=0;
    while (MyBT.available() > 0 && i < 31) { 
        received_message[i++] = MyBT.read();
        delay(4);
    }
    //received_message[i] = '\0';

    Serial.print(received_message);

    if (strstr(received_message, "F")){
      float R_flex= Flex_Mesure();
      MyBT.print(R_flex);
    }
    if (strstr(received_message, "G")){
      int R_graph = Graphite_Mesure();
      MyBT.print(R_graph);
    }

  delay(10);
  }
}



//====================================================
//==================== Functions =====================
//====================================================

//==================== Function for OLED Screen ====================
      // The initailise the OLED screen's parameters
void Set_OLED() {
  if (!ecranOLED.begin(SSD1306_SWITCHCAPVCC, adresseI2CecranOLED)) {
    Serial.println("Initialisation OLED screen NO");
  }
  ecranOLED.clearDisplay();         // Effacage de l'intégralité du buffer
  InitOLED();
  ecranOLED.println(F("Main Menu:"));
  ecranOLED.println(F(">Fonction")) ;
  ecranOLED.println(F(">Capteur")) ;
  ecranOLED.display();
}
void InitOLED(){
  ecranOLED.clearDisplay();
  ecranOLED.setTextSize(2);
  ecranOLED.setCursor(0, 0);
  ecranOLED.setTextColor(SSD1306_WHITE, SSD1306_BLACK);
}
      // OLED_CouleurInverse(bool Inverser): Si vrai alors inverse la couleur: texte en noir en fond en blanc
void OLED_CouleurInverse(bool Inverser) {
  if (Inverser == true) {
    ecranOLED.setTextColor(SSD1306_BLACK, SSD1306_WHITE);       // (Couleur du texte: BLACK, Couleur du fond: WHITE)
  }
  else {
    ecranOLED.setTextColor(SSD1306_WHITE, SSD1306_BLACK);
  }
}
      // 1er indice indique le niveau du menu, 2nd indice indique le choix
void OLED_Menu0_0(int Val) {
  InitOLED();
  ecranOLED.println(F("Main Menu:"));
  switch (Val){
    case 0 :
      OLED_CouleurInverse(true) ;
      ecranOLED.println(F(">Fonction")) ;
      OLED_CouleurInverse(false) ;
      ecranOLED.println(F(">Capteur")) ;
      MenuPos = 0;
      break;
    case 1 :
      ecranOLED.println(F(">Fonction")) ;
      OLED_CouleurInverse(true) ;
      ecranOLED.println(F(">Capteur")) ;
      OLED_CouleurInverse(false) ;
      MenuPos = 1;
      break;
    default :
      ecranOLED.println(F(">Fonction")) ;
      ecranOLED.println(F(">Capteur")) ;
      MenuPos = -1;
      break;
  }
  ecranOLED.display();
}
      // Menu de Niveau 1, choix 0 du Niveau 0.
void OLED_Menu1_0(int Val) {
  InitOLED();
  ecranOLED.println(F("Fonction:"));
  switch (Val){
    case 0 :
      OLED_CouleurInverse(true) ;
      ecranOLED.println(F(">Fonction1")) ;        // Prise de Mesure
      OLED_CouleurInverse(false) ;
      ecranOLED.println(F(">Fonction2")) ;
      ecranOLED.println(F("<<Exit")) ;
      MenuPos = 100;
      break;
    case 1 :
      ecranOLED.println(F(">Fonction1")) ;
      OLED_CouleurInverse(true) ;
      ecranOLED.println(F(">Fonction2")) ;
      OLED_CouleurInverse(false) ;
      ecranOLED.println(F("<<Exit")) ;
      MenuPos = 101;
      break;
    case 2 :
      ecranOLED.println(F(">Fonction1")) ;
      ecranOLED.println(F(">Fonction2")) ;
      OLED_CouleurInverse(true) ;
      ecranOLED.println(F("<<Exit")) ;
      OLED_CouleurInverse(false) ;
      MenuPos = 102;
      break;
    default :
      ecranOLED.println(F(">Fonction1")) ;
      ecranOLED.println(F(">Fonction2")) ;
      ecranOLED.println(F("<<Exit")) ;
  }
  ecranOLED.display();
}
      // Menu de Niveau 1, choix 1 du Niveau 0.
void OLED_Menu1_1(int Val) {
  InitOLED();
  ecranOLED.println(F("Capteur:"));
  switch (Val){
    case 0 :
      OLED_CouleurInverse(true) ;
      ecranOLED.println(F(">Capteur1")) ;
      OLED_CouleurInverse(false) ;
      ecranOLED.println(F(">Capteur2")) ;
      ecranOLED.println(F("<<Exit")) ;
      MenuPos = 110;
      break;
    case 1 :
      ecranOLED.println(F(">Capteur1")) ;
      OLED_CouleurInverse(true) ;
      ecranOLED.println(F(">Capteur2")) ;
      OLED_CouleurInverse(false) ;
      ecranOLED.println(F("<<Exit")) ;
      MenuPos = 111;
      break;
    case 2 :
      ecranOLED.println(F(">Capteur1")) ;
      ecranOLED.println(F(">Capteur2")) ;
      OLED_CouleurInverse(true) ;
      ecranOLED.println(F("<<Exit")) ;
      OLED_CouleurInverse(false) ;
      MenuPos = 112;
      break;
    default :
      ecranOLED.println(F(">Capteur1")) ;
      ecranOLED.println(F(">Capteur2")) ;
      ecranOLED.println(F("<<Exit")) ;
      break;
  }
  ecranOLED.display();
}
void ExitMenu(){
  Serial.println("Exit");
  encoderButton = 0 ;
  encoderPos = 0 ;
  MenuPos = -1 ;
  MenuPosBefore = -1;
}
      // DisplayOLED(): Fonction d'affichage de l'écran OLED 
void DisplayOLED() {
  if ( (encoderPosBefore != encoderPos) || (encoderButtonBefore != encoderButton) ) {
    if (encoderButtonBefore != encoderButton) {
      MenuPosBefore = MenuPos ;
      encoderButtonBefore = encoderButton;
      encoderPos = 0;
    }

    switch (encoderButton) {
      case 0 :
        OLED_Menu0_0(abs(encoderPos % 2));     // encoder modulo nb de choix - 1
        break;
      case 1 :
        if (MenuPosBefore == 0) {               // Menu Fonction
          OLED_Menu1_0(abs(encoderPos % 3));
        }
        else if (MenuPosBefore == 1) {          // Menu Capteur
          OLED_Menu1_1(abs(encoderPos % 3));
        }
        break;
      case 2 :
        switch (MenuPosBefore) {
          case 100 :                            // Fonction 1: Prise de mesure
            InitOLED();
            OLED_CouleurInverse(true) ;
            ecranOLED.println(F(">Fonction1")) ;
            OLED_CouleurInverse(false) ;
            ecranOLED.display();
            // setPotWiper(pot0, 128);
            MenuPosBefore = 100 ;
            break;
          case 101 :                            // Fonction 2
            InitOLED();
            OLED_CouleurInverse(true) ;
            Serial.println(F("Fonction 2"));
            OLED_CouleurInverse(false) ;
            ecranOLED.display();
            // setPotWiper(pot0, 255);
            MenuPosBefore = 101 ;
            break;
          case 102 :
            ExitMenu();
            break;
          case 110 :                             // Capteur1: Flex Sensor
            InitOLED();
            OLED_CouleurInverse(true) ;
            ecranOLED.println(F("FlexSensor")) ;
            OLED_CouleurInverse(false) ;
            ecranOLED.display();
            MenuPosBefore = 110 ;
        
            ChoixCapteur = 110 ;
            
            break;
          case 111 :                             // Capteur2: Graphite Sensor
            InitOLED();
            OLED_CouleurInverse(true) ;
            ecranOLED.println(F("Graphite")) ;
            OLED_CouleurInverse(false) ;
            ecranOLED.display();
            MenuPosBefore = 111 ;
            ChoixCapteur = 111 ;
            
            break;
          case 112 :
            ExitMenu();
            break;
        }
        break;
      case 3:
        break;
      default:
        InitOLED();
        ecranOLED.println(F("Main Menu:")) ;
        ecranOLED.println(F(">Fonction")) ;
        ecranOLED.println(F(">Capteur")) ;
        ecranOLED.display();
        encoderButton = 0 ;
        encoderButtonBefore = encoderButton;
        encoderPos = 0;
        MenuPos = -1 ;
        MenuPosBefore = -1;
        ChoixCapteur = 0;
    }
    encoderPosBefore = encoderPos;
  }
}

//==================== Function for Rotary encoder ====================
      // Initialise the Rotary encoder
void Set_RotaryEncoder(){
  pinMode(pinEncoder_CLK, INPUT);
  digitalWrite(pinEncoder_CLK, HIGH);
  pinMode(pinEncoder_DT, INPUT);
  digitalWrite(pinEncoder_DT, HIGH);
  pinMode(pinEncoder_SW, INPUT);
}
      // To get the encoder position
void doEncoder() {
  if (digitalRead(pinEncoder_CLK) == HIGH && digitalRead(pinEncoder_DT) == HIGH) {
    encoderPos-- ;
  }
  else if (digitalRead(pinEncoder_CLK) == HIGH && digitalRead(pinEncoder_DT) == LOW) {
    encoderPos++ ;
  }

  Serial.print("encoderPos=");
  Serial.print(encoderPos);
  Serial.print(" ; encoderButtonBefore=");
  Serial.print(encoderButtonBefore);
  Serial.print(" ; encoderButton=");
  Serial.print(encoderButton);
  Serial.print(" ; MenuPos=");
  Serial.println(MenuPos);
}
      // To get the position of the encoder's button
void doEncoderButton() {
  int valeur = digitalRead(pinEncoder_SW) ;
  if (valeur != lastButtonState){
    lastDebounceTime = millis();
  }
  if ((millis() - lastDebounceTime)> debounceDelay){
    if ( (valeur == LOW) && (valeur != buttonState) ){
      encoderButton++ ;
    }
    buttonState = valeur ;
  }
  lastButtonState = valeur ;
}

//==================== Function for Sensors ====================
        //========== flex Sensor ==========
float Flex_Mesure(){
  //Calculation of the flex sensor's resistance
  int ADC_flex = analogRead(pinFlexSensor);
  float V_flex = (ADC_flex * VCC) / 1023.0;
  float R_flex = R_DIV * ( V_flex / (VCC-V_flex));
  long angle  = map(R_flex, flatResistance, bendResistance, 0, 90);

  return R_flex; 
}
        //========== Graphite Sensor ==========
float Graphite_Mesure(){
  //Calculation of the Graphite sensor's resistance
  int mesure = analogRead(pinGraphiteSensor);
  float V_ADC = mesure * VCC / 1023.0 ;
  float R_graph = (1+R3/R_pot)*R1*(VCC/V_ADC)-(R1+R5) ;
  
  return R_graph;
}
        //========== Capteur Global Function ==========
void Sensor_Mesurement(int PositionMenu){
  switch (PositionMenu){
    case 110:                             // Flex Sensor
      DataToSend = Flex_Mesure();
      break;
    case 111:                             // Graphite Sensor
      DataToSend = Graphite_Mesure();
      break;
    default:
      break;
  }
}

//==================== Digital Potentiometer ====================
      // Initialise the Digital Potentiometer
void Set_DigitalPotentiometer(){
  pinMode(pinPot_CS, OUTPUT);
  digitalWrite(pinPot_CS, HIGH);
  SPI.begin();
  setPotWiper(pot0, 128);
}
void setPotWiper(int addr, int pos){
  pos = constrain(pos, 0, 255);            // limit wiper setting to range of 0 to 255
  digitalWrite(pinPot_CS, LOW);                // select chip
  SPI.transfer(addr);                      // configure target pot with wiper position
  SPI.transfer(pos);
  digitalWrite(pinPot_CS, HIGH);               // de-select chip

  // print pot resistance between wiper and B terminal
  R_pot = ((rAB * pos) / maxPositions ) + rWiper ;
}

//==================== Function for Bluetooth ====================
      // Initialise the Bluetooth
void InitBluetooth(){
  pinMode(pinBT_RXD, INPUT);
  pinMode(pinBT_TXD, OUTPUT);
  MyBT.begin(baudrate);
}

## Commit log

2025-03-05 fini la context readme
2025-03-05 Diagramme GANNT
    [Diagramme GANNT.xlsx]
2025-03-05 add LTspice
    [OSSD-128x64.igs, OSSD-128x64.x_b, projet_capteur.kicad_pcb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]
2025-03-05 add modul oled et bluetooth
    [OSSD-128x64.igs, OSSD-128x64.x_b]
2025-03-12 add 3D model to OLED
    [Pantalla OLED 0.96'' 128x64.stp, projet_capteur.kicad_pcb, projet_capteur.kicad_sch]
2025-03-12 add symbol encoder
2025-03-12 Ajout FlexSensor
    [projet_capteur.kicad_pcb, projet_capteur.kicad_sch]
2025-03-12 Add bluetooth and encoder symbol into Schematic
    [projet_capteur.kicad_sch]
2025-03-12 Ajout symbole FlexSensor
    [projet_capteur.kicad_sch]
2025-03-12 add model 3D flex sensor and rotary encoder
    [FlexSensor.SLDASM, Flex_Sensor_Circuit.SLDPRT, GoldProngTerminal.SLDPRT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]
2025-03-12 Modification OLED
    [projet_capteur.kicad_sch]
2025-03-12 add data flex sensor
2025-03-12 add symbol graphite sensor
    [projet_capteur.kicad_sch]
2025-03-12 add symbol LTC1050
    [projet_capteur.kicad_sch]
2025-03-12 Save sth
    [projet_capteur.kicad_sch]
2025-03-12 Add empreintes into PCB
    [projet_capteur.kicad_pcb]
2025-03-12 modify schema symbol
    [projet_capteur.kicad_sch]
2025-03-12 Schématique
    [projet_capteur.kicad_pcb, projet_capteur.kicad_sch]
2025-05-29 add projet on github
    [10-Pin Header - Male - 2.54mm.step, 11-Pin Header - Male - 2.54mm.step, 12-Pin Header - Male - 2.54mm.step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]
2025-05-29 modify banc de test
    [MesureGraphiteSensor.xlsx, banc_de_test.xlsx]
